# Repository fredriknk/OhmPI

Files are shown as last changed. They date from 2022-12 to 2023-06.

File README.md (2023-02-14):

# OhmPi



Development of a low-cost multi-electrodes resistivity meter for electrical resistivity mesaurement for lab applications, based on raspberry board

## Installation

All dependencies are specified in *requirements.txt*

**Note:** all instructions below should be typed in the terminal

It is first necessary to create an OhmPi virtual environment and install all dependancies
`.create_ohmpi_virtual_envrinment.sh`

When the installation is completed check that requirements are met using 
`pip list`

We strongly recommend users to create a virtual environment to run the code and installed all required dependencies:
*  activate it using the following command:
   `source ohmpy/bin/activate`
*  you should run you code within the virtual environment
*  to leave the virtual environment simply type: `deactivate`

## First run with four electrodes

In the examples folder, you will find the code "simple_measurement.py".

Running this code, in Thonny (IDE) or in the terminal, will allow you to make a simple 4 electrodes measurement A B M N.

## Citing Ohmpi

If you use Ohmpi for you work, please cite [this paper](https://www.sciencedirect.com/science/article/pii/S2468067220300316) as:

    Rémi Clement, Yannick Fargier, Vivien Dubois, Julien Gance, Emile Gros, Nicolas Forquet, OhmPi: An open source data logger for 
    dedicated applications of electrical resistivity imaging at the small and laboratory scale, HardwareX, Volume 8, 2020, e00122, ISSN 2468-0672, https://doi.org/10.1016/j.ohx.2020.e00122..

## License information

You may redistribute and modify this documentation and make products using it under the terms of the CERN-OHL-P v2 (https:/cern.ch/cern-ohl). This documentation is distributed WITHOUT ANY EXPRESS OR IMPLIED WARRANTY, INCLUDING OF MERCHANTABILITY, SATISFACTORY QUALITY AND FITNESS FOR A PARTICULAR PURPOSE. Please see the CERN-OHL-P v2 for applicable conditions

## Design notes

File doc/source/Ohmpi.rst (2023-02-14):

*************** 
OhmPi project 
***************

    Logo OhmPi

|  

**Authors:** 
------------
| Rémi CLEMENT, Vivien DUBOIS, Nicolas Forquet, INRAE, REVERSAAL, Villeurbanne, France
| Yannick FARGIER, GERS-RRO, Univ Gustave Eiffel, IFSTTAR, Lyon, France
| Hélène GUYARD, IGE Grenoble, Université Grenoble Alpes, Grenoble, France
| Olivier KAUFMANN, Arnaud WATLET, Université de Mons, Mons, Belgium
| Guillaume BLANCHY, ILVO, Merelbeke, Belgium|

**Partners:**
-------------

.. table::
   :align: center
  
   +----------------------------------+-----------------------------------+-------------------------------+
   |   
   +----------------------------------+-----------------------------------+-------------------------------+
   |   
   +----------------------------------+-----------------------------------+-------------------------------+

**Citing OhmPi:** 
-----------------

|

*Rémi Clement, Yannick Fargier, Vivien Dubois, Julien Gance, Emile Gros, et al.. OhmPi: An open*
*source data logger for dedicated applications of electrical resistivity imaging at the small and laboratory*
*scale. HardwareX, Elsevier, 2020, 8, 24 p. ff10.1016/j.ohx.2020.e00122ff.*

|
   
**Introduction :** 
-------------------

.. warning::
    **OhmPi is a participative project open to all, it requires skills in electronics and to respect the safety rules. OhmPi must be assembled in a professional context and by people competent in electronics. The OhmPi team cannot be held responsible for any material or human damage which would be associated with the use or the assembly of OhmPi. The OhmPi team cannot be held responsible if the equipment does not work after assembly. You may redistribute and modify this documentation and make products using it under the terms of the CERN-OHL-P v2 (https:/cern.ch/cern-ohl). This documentation is distributed WITHOUT ANY EXPRESS OR IMPLIED WARRANTY, INCLUDING OF MERCHANTABILITY, SATISFACTORY QUALITY AND FITNESS FOR A PARTICULAR PURPOSE. Please see the CERN-OHL-P v2 for applicable conditions   **

|

This documentation presents the development of a low-cost, open hardware \ 
resistivity meter to provide the scientific community with a robust \
and flexible tool for small-scale experiments. Called OhmPi, this basic resistivity meter\
features current injection and measurement functions associated with a multiplexer \
that allows performing automatic measurements with up to 64 electrodes.\
OhmPi's philosophy is to provide a fully open source and open hardware tool\
to the near surface scientific community.

.. note:: 
   Anyone who wants to get involved is welcome to join the OhmPi project!

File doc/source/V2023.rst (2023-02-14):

********************************************
OhmPi V2023 (64 electrodes and 12V)
******************************************** 

.. warning::
  **OhmPi is a participative project open to all, it requires skills in electronics and to respect the safety rules. OhmPi must be assembled in a professional context and by people competent in electronics. The OhmPi team cannot be held responsible for any material or human damage which would be associated with the use or the assembly of OhmPi. The OhmPi team cannot be held responsible if the equipment does not work after assembly.**

OhmPi V: 2023.0.0-rc1

.. note:: 
   In this version, we have developed two new board types that allow the assembly of OhmPi v2023, a measurement board and a multiplexer board.
   This new version is made up of:

   1. A measurement board for four-point measurement

   2. 4 multiplexer cards

   3. A box

  The OhmPi V2023 software has been adapted to handle this new boards and also includes many new functionalities.

The philosophy of OhmPi
========================

The philosophy of OhmPi V2023 is to offer a new DIY multi-electrode resistivity meter. It is a resistivity meter with 64 electrodes, which can be upgraded to 128 electrodes.
It is limited to low-current injection, but suitable for small laboratory experiments and small field time-lapse monitoring.
OhmPi is developed by a team that seeks to share its experience and wishes to improve and offer a more and more robust tool to the community. OhmPi 2023 is completely different version from the previous one. 
We will stop the development on the version V1.0x, to dedicate our efforts on this new version.

=============================================================================================================================================================

Hardware
========

Specifications
--------------

+-------------------------------+-----------------------+-----------+-----------------------+-----------+
| **Parameter**                 |       **V1.0x**       | Units     |       **v2023**       | Units     |
+===============================+=======================+===========+=======================+===========+
|Electrodes                     |32                     |           |64 to 128              |           |
+-------------------------------+-----------------------+-----------+-----------------------+-----------+
|Operating temperature          |-0 to 50               |°c         |-25 to 50              |°C         |
+-------------------------------+-----------------------+-----------+-----------------------+-----------+
|Power consumption of CPU and   |18.5                   |W          |18.5                   |W          |
|control system                 |                       |           |                       |           |
+-------------------------------+-----------------------+-----------+-----------------------+-----------+
|Voltage injection              |12                     |V          |12                     |V          |
+-------------------------------+-----------------------+-----------+-----------------------+-----------+
|Battery                        |9                      |V          |12                     |V          |
+-------------------------------+-----------------------+-----------+-----------------------+-----------+
|Current                        |0 to 40                |mA         |0 to 40                |mA         |
+-------------------------------+-----------------------+-----------+-----------------------+-----------+
|Min pulse duration             |150                    |ms         |150                    |ms         |
+-------------------------------+-----------------------+-----------+-----------------------+-----------+
|Input impedance                |80                     |MOhm       |80                     |MOhm       |
+-------------------------------+-----------------------+-----------+-----------------------+-----------+
|Data storage                   |micro SD card          |           |micro SD card          |           |
+-------------------------------+-----------------------+-----------+-----------------------+-----------+
|Resolution                     |0.01                   |Ohm        |0.01                   |Ohm        |
+-------------------------------+-----------------------+-----------+-----------------------+-----------+

Building an OhmPi V2023 step by step
------------------------------------

.. toctree::
   :maxdepth: 2

   Ohmpi_V2023/V2023_step_01
   Ohmpi_V2023/V2023_step_02
   Ohmpi_V2023/V2023_step_03
   Ohmpi_V2023/V2023_step_04

Software and operation
======================

System architecture
-------------------

The OhmPi V2023 software is designed around a new architecture whose main components are summarized in the figure below.

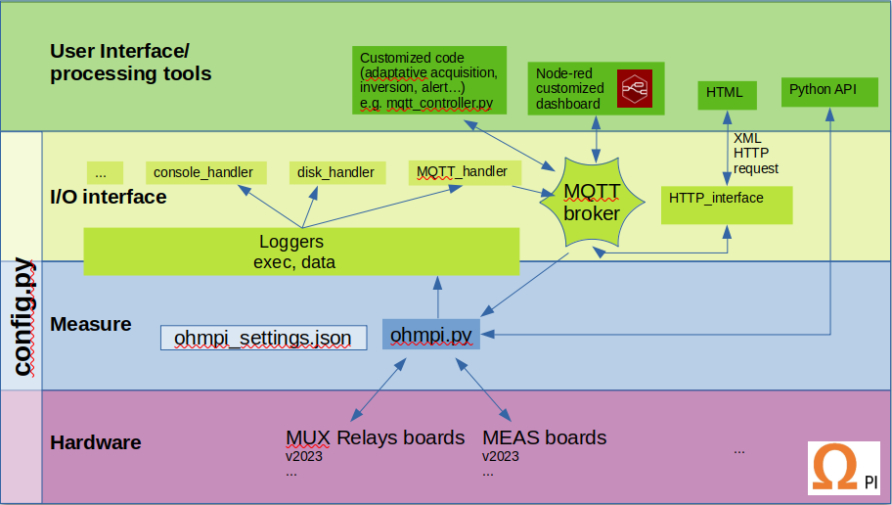
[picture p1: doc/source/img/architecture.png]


     Software architecture of OhmPi V2023.

The general system configuration is defined in the `config.py` file covered in the `Configuration file`_ section.
The acquisition settings (i.e. injection duration, stacks...) are defined in a separate JSON file (default: ohmpi_settings.json).  

The central software component is the ohmpi.py file that contains the OhmPi class that interacts with the hardware. Other python files include utils and handlers (see the `Loggers`_ section for more details).
A communication layer (I/O interface) on top of OhmPi allows for different user interfaces depending on the use cases (see `Interfaces and applications`_).

Loggers
-------

Loggers have been introduced in this release. They use the excellent logging python package.
Specific handlers have been implemented for running with ohmpi.py (one for logging to an mqtt broker (see `MQTT interface`_ for more details) and one for creating zipped rotated logs on disk).

Two loggers have been defined. The first one is dedicated to log operations execution. It is named exec_logger. The second one, named data_logger, is dedicated to log data. A third one is planned to log the state of health (SOH) of the system in a future version.

By default, logs are written to the console (print-like), stored locally in files (a zip is created after some time i.e. every day and/or when the size of the log exceeds a maximum size) and sent to an MQTT broker. Different logging levels may be defined for the different logs and handlers in the `Configuration file`_.

Advanced users may write new handlers and edit the `setup_loggers.py` file to customize the logging mechanisms to their needs.

Configuration file
------------------

The configuration of the OhmPi file `config.py` allows to configure the OhmPi.
A default version of `config.py` is provided in the repository.
This file should be edited to customize the configuration following the user's needs and preferences.  

The configuration includes setting the logging level desired for the different loggers and handlers, setting the mqtt broker(s) used for logging and control of the OhmPi and defining the options used for MQTT communication (i.e. username, password, security options...)  

One should make sure to understand the parameters before altering them. It is also recommended to keep a copy of the default configuration.

Interfaces and applications
---------------------------

Different interfaces can be used to interact with the OhmPi.

Available interfaces are:
- `Web interface`_ (=HTTP interface): run in bash: `bash run_http_interface.sh`
- Python API: import the OhmPi class from Python script: `from ohmpi import OhmPi` (see `Python interface`_)
- MQTT: IoT messaging through a broker (see `MQTT interface`_)

Web interface
.............

This is a user friendly graphical interface for new users as well as running quick and easy acquisitions.

The Raspberry Pi of the OhmPi is used as a Wi-Fi Access Point (AP) and runs
a small webserver to serve the 'index.html' interface. Using a laptop or
a mobile phone connected to the Wi-Fi of the Raspberry Pi, one can see this
interface, upload sequences, change parameters, run a sequence and download data.

To configure the Raspberry Pi to act as an access point and run
the webserver automatically on start, see instructions on `raspap.com <https://raspap.com/>`_ and in 'runOnStart.sh'.

Once configured, the webserver should start by itself on start and once
connected to the Pi, the user can go to `10.3.141.1:8080 <http://10.3.141.1:8080>`_
to access the interface.



    Web interface with its interactive pseudo-section.



     Evolution of quadrupole apparent resistivity with time.



     Contact resistance check.

Python interface
................

This interface offers a more direct access to the software components especially well suited for testing or automation on the Raspberry Pi.

By importing the `OhmPi` class from the ohmpi.py, one can control the OhmPi using interactive IPython.
Typically, it involves using the terminal or an Python IDE such as Thonny on the Raspberry Pi. One can also connect using
ssh and run the Python interface (see PuTTY on Windows or ssh command on macOS/Linux).

To access the Python API, make sure the file ohmpi.py is in the same
directory as where you run the commands/script. The file ohmpi.py can
be found on the OhmPi gitlab repository. We recommend downloading the
entire repository as ohmpi.py import other .py files and default configuration
files (.json and .py).

.. code-block:: python
  :caption: Example of using the Python API to control OhmPi

  import os
  import numpy as np
  import time
  os.chdir("/home/pi/OhmPi")
  from ohmpi import OhmPi

  ### Define object from class OhmPi
  k = OhmPi()  # this loads default parameters from the disk

  ### Default parameters can also be edited manually
  k.settings['injection_duration'] = 0.5  # injection time in seconds
  k.settings['nb_stack'] = 1  # one stack is two half-cycles
  k.settings['nbr_meas'] = 1  # number of time the sequence is repeated

  ### Update settings if needed
  k.update_settings({"injection_duration":0.2})

  ### Set or load sequence
  k.sequence = np.array([[1,2,3,4]])    # set numpy array of shape (n,4)
  # k.set_sequence('1 2 3 4\n2 3 4 5')    # call function set_sequence and pass a string
  # k.load_sequence('ABMN.txt')    # load sequence from a local file

  ### Run contact resistance check
  k.rs_check()

  ### Run sequence (synchronously - it will wait that all
  # sequence is measured before returning the prompt
  k.run_sequence()
  # k.run_sequence_async()  # sequence is run in a separate thread and the prompt returns immediately
  # time.sleep(2)
  # k.interrupt()  # kill the asynchron sequence

  ### Run multiple sequences at given time interval
  k.settings['nb_meas'] = 3  # run sequence three times
  k.settings['sequence_delay'] = 100 # every 100 s
  k.run_multiple_sequences()  # asynchron
  # k.interrupt()  # kill the asynchron sequence

  ### Single measurement can also be taken with
  k.switch_mux_on([1, 4, 2, 3])
  k.run_measurement()  # use default acquisition parameters
  k.switch_mux_off([1, 4, 2, 3])  # don't forget this! risk of short-circuit

  ### Custom or adaptative argument, see help(k.run_measurement)
  k.run_measurement(nb_stack=4,  # do 4 stacks (8 half-cycles)
                    injection_duration=2,  # inject for 2 seconds
                    autogain=True)  # adapt gain of ADS to get good resolution

MQTT interface
..............

This is an interface designed for an advanced remote usage of the OhmPi such as remote automation, data consumption by multiple processes and interaction with other sensors in the scope of a monitoring. It is based on the MQTT protocol, designed for the Internet of Things (IoT), to interact with the OhmPi.  

This option allows interacting remotely with a single OhmPi, a network of OhmPis, as well as auxiliary instruments and sensors. The communication is based on a publish/subscribe approach and involves a MQTT broker.  

An example of MQTT broker that can be used is `Mosquitto <https://mosquitto.org/>`_. Depending on the monitoring needs, an MQTT broker can be set up locally on the Raspberry Pi, on a local network or any remote server reachable through the net. A local Mosquitto broker can be set up and enabled to run as a service on the OhmPi using the bash script install_local_mqtt_broker.sh.  

MQTT messages include logging messages from the OhmPi and commands sent to the OhmPi. These messages can be examined easily using a third party software such as `MQTT Explorer <http://mqtt-explorer.com/>`_.

Commands sent on the broker are received by the ohmpi.py script that runs on the OhmPi (make sure ohmpi.py starts on reboot) and further processed.
MQTT commands are sent in JSON format following the Python API with kwargs as illustrated below:

.. code-block:: json
  :caption: Updating acquisition settings.

  {
    "cmd_id": "3fzxv121UITwGjWYgcz4xw",
    "cmd": "update_settings", Depending on the experiment needs, MQTT brokers can be set up locally on the Raspberry Pi or on a local or remote server.
    "kwargs": {
      "config": {
        "nb_meas": 2,
        "nb_electrodes": 10,
        "nb_stack": 2,
        "injection_duration": 2,
        "sequence_delay": 100
      }
    }
  }

.. code-block:: json
  :caption: Check contact resistances

  {
    "cmd_id": "3fzxv121UITwGjWYgcz4xw",
    "cmd": "rs_check",
  }

.. code-block:: json
  :caption: Running a sequence.

  {
    "cmd_id": "3fzxv121UITwGjWYgcz4Yw",
    "cmd": "run_sequence",
  }

.. code-block:: json
  :caption: Running same sequence multiple times (nb_meas).

  {
    "cmd_id": "3fzxv121UITwGjWYgcz4Yw",
    "cmd": "run_multiple_sequences",
  }

.. code-block:: json
  :caption: Interrupt current acquisition.

  {
    "cmd_id": "3fzxv121UITwGjWYgcz4xw",
    "cmd": "interrupt",
  }

Custom processing of messages and tailor-made dashboards for monitoring experiments may be designed using a browser-based flow editor such as `Node-red <http://mqtt-explorer.com/>`_.
This may help designing complex IoT experiments and monitoring systems in which OhmPi is a component. 

Examples incorporating execution commands and data outputs from OhmPi can be found in the OhmPi examples. Once Node-RED is installed on the OhmPi, these examples can be accessed separately by running a command in the console such as :

.. code-block:: console
     node-red basic_ohmpi_flows_node-red.json

These examples may require installing some additional node packages in order to work properly. This can be done in the `Palette Manager <https://nodered.org/docs/user-guide/editor/palette/manager> within Node-RED.

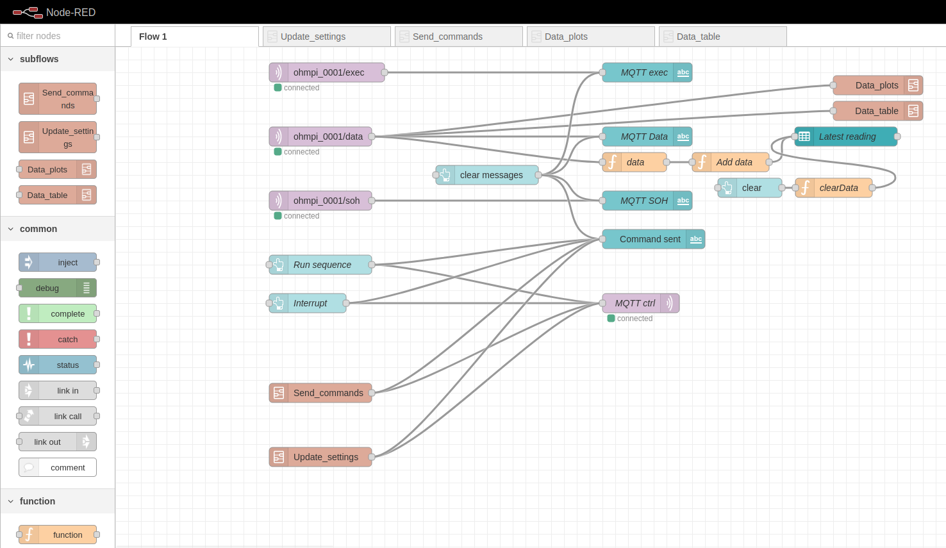
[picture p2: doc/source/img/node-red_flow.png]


     Example flow in node-red to interact with an OhmPi.

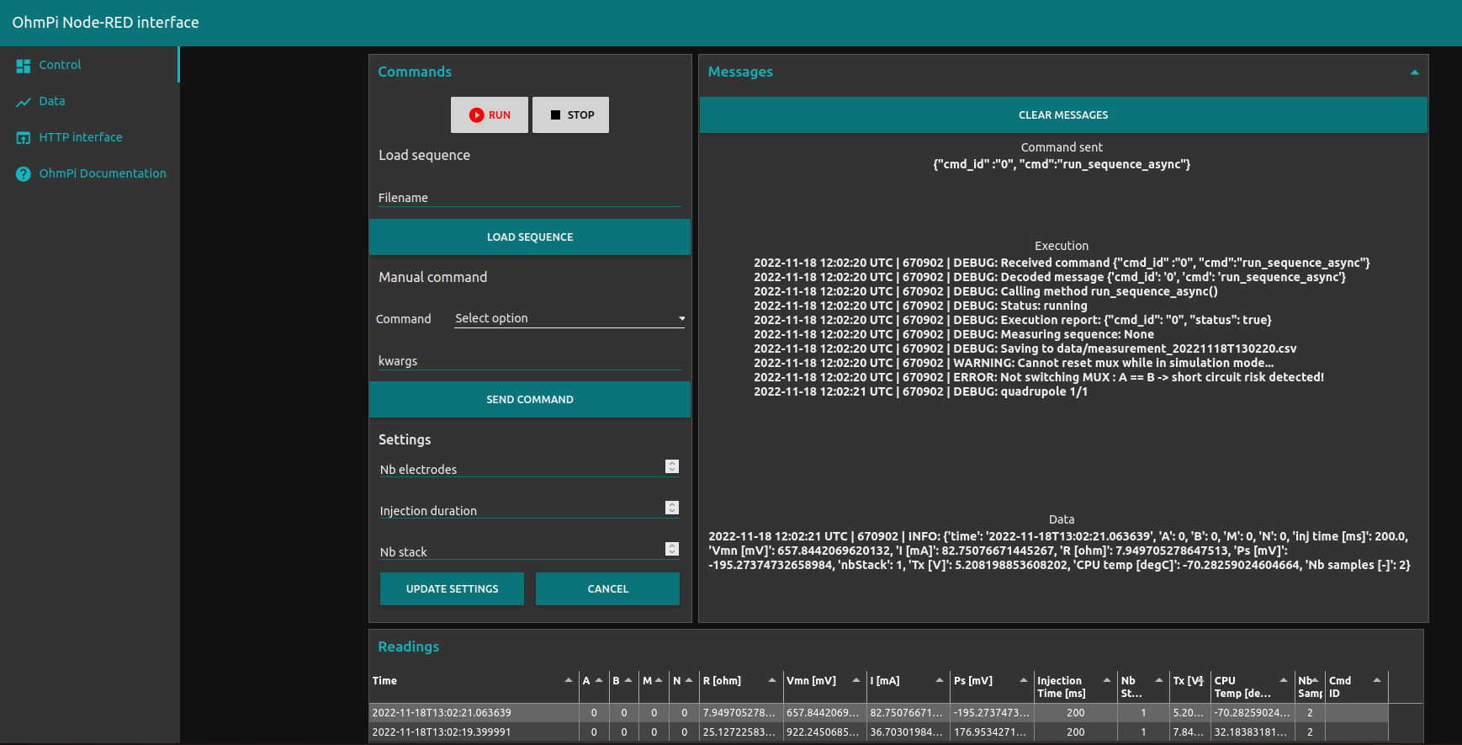
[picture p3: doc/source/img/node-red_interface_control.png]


     Example of a dashboard UI created with node-red to interact with an OhmPi - control tab.
     
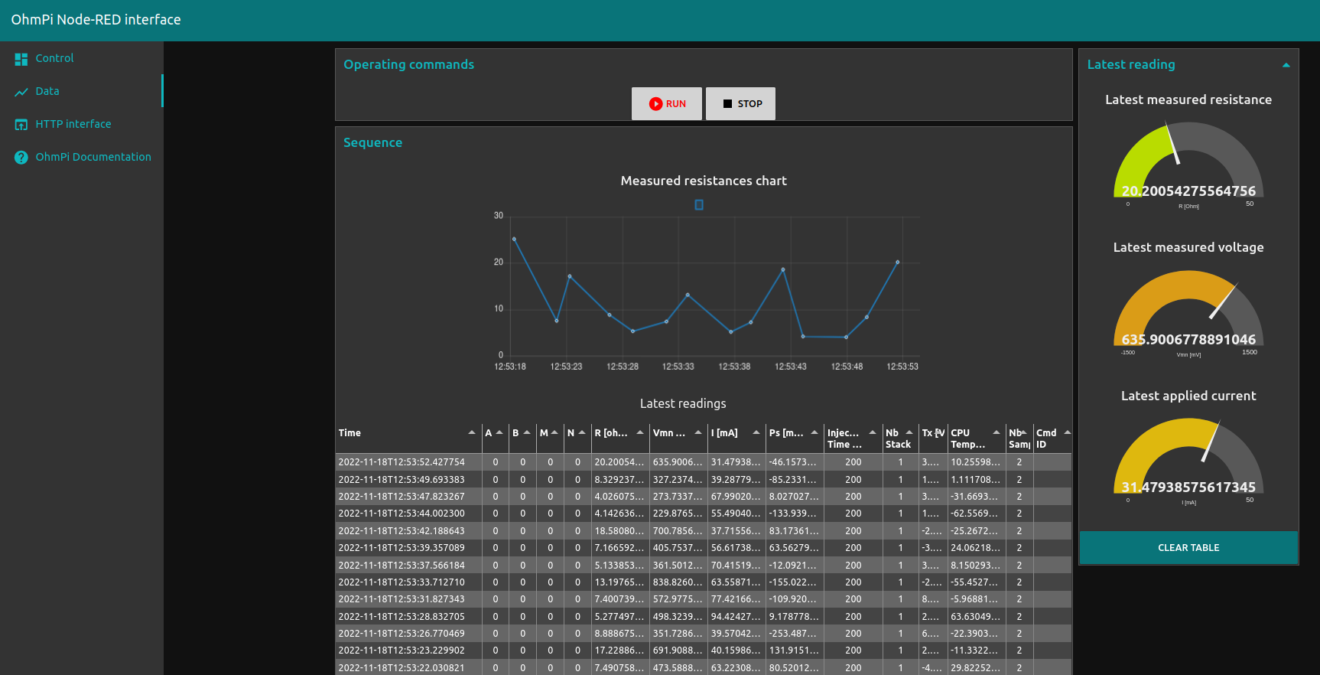
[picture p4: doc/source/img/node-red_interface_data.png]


     Example of a dashboard UI created with node-red to interact with an OhmPi - data visualization tab.

For more documentation dedicated to node-red, please refer to the Node-red `cookbooks <https://cookbook.nodered.org/>`_.

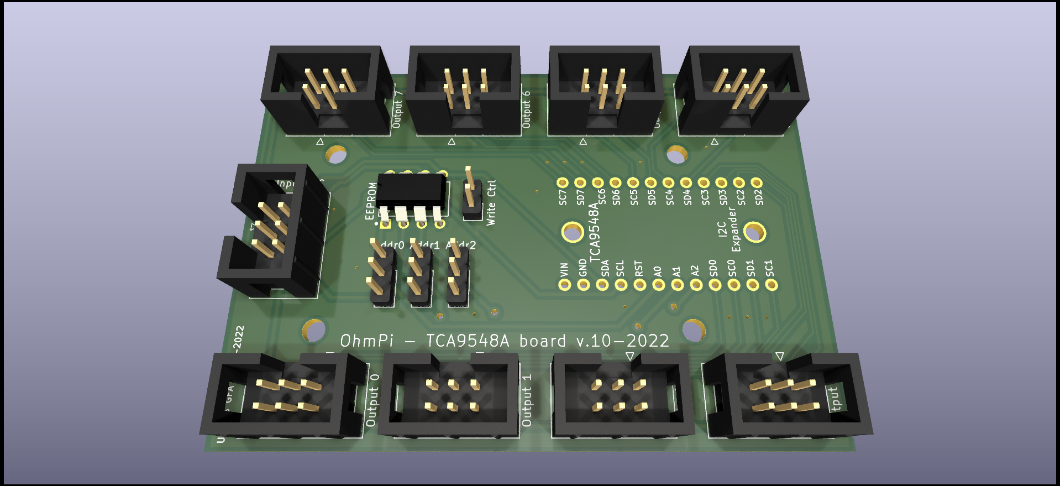
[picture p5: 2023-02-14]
MUX_board/2024.0.0/tca_board/TCA_board_2.png

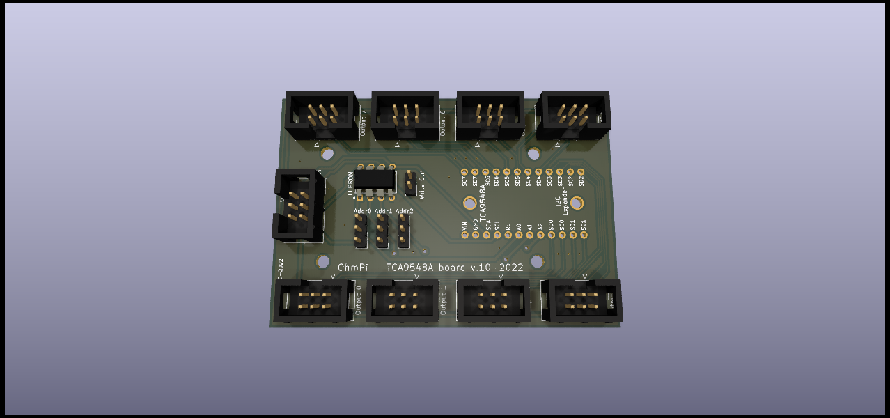
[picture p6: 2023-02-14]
MUX_board/2024.0.0/tca_board/MUX_v2024_tca_board.png

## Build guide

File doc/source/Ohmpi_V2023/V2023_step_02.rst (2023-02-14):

**STEP n°2**: Measurement board
****************************************************

.. warning::
    **Ohmpi is a participative project open to all, it requires skills in electronics and to respect the safety rules. OhmPi must be assembled in a professional context and by people competent in electronics. The OhmPi team cannot be held responsible for any material or human damage which would be associated with the use or the assembly of OHMPI. The OhmPi team cannot be held responsible if the equipment does not work after assembly.**

**PART A** Assembly of the measurement board
======================================================

Required components 
----------------------------------------------------

alternate text

.. csv-table:: List of components
   :file: step_n_2/a/measure_board_list_2_xx.csv
   :widths: 30, 70, 70, 70, 70, 35, 35
   :header-rows: 1
   
Description
------------------  

alternate text

Figure  shows the general schematics for the electronic measurement board developed.
We have developed a complete "plug and play" measurement board. To measure electrical resistivity with Raspberry Pi. 
two ADS1115 were used,one for the voltage measurement one for the current measurement, as proposed by Florsch [7]. The ADS1115
is a 16-bit ADC (Analog-to-Digital Converter), with an adaptable gain. The advantage of ADS1115 is that the 
input signal value could lie between - to + 6.114 V. For the current measurement we have directly integrated the INA282 component, 
which allows to realize precise current measurement around a shunt resistor. The assembly are described in the following steps:

.. table::
   :align: center
   
   +--------+------------------------------------------------------------+
   |        |   
   |      1 +------------------------------------------------------------+
   |        | Installation of female header, 1 by 10  pins, for ADS1115  | 
   |        |                                                            |                                                                       
   +--------+------------------------------------------------------------+
   
.. table::
   :align: center
  
   +--------+------------------------------------------------------------+
   |        |   
   |2       +------------------------------------------------------------+
   |        | Soldering of 4 dual-in-line socket (2 by 2 pins) for       | 
   |        | optical relay, AQY211EH.                                   |                                                                       
   +--------+------------------------------------------------------------+
   
.. table::
   :align: center
  
   +--------+------------------------------------------------------------+
   |        |   
   |3       +------------------------------------------------------------+
   |        | Soldering of 1 dual-in-line socket (2 by 9 pins)           | 
   |        | for MCP23008.                                              |                                                                       
   +--------+------------------------------------------------------------+
   
.. table::
   :align: center
  
   +--------+------------------------------------------------------------+
   |        |   
   | 4      +------------------------------------------------------------+
   |        | Soldering of 1 dual-in-line socket (2 by 4 pins)           | 
   |        |                                                            |                                                                       
   +--------+------------------------------------------------------------+ 
.. table::
   :align: center
  
   +--------+------------------------------------------------------------+
   |        |   
   |5       +------------------------------------------------------------+
   |        | Soldering of 2 dual-in-line socket (2 by 4 pins)           | 
   |        |                                                            |                                                                       
   +--------+------------------------------------------------------------+
   
.. table::
   :align: center
  
   +--------+------------------------------------------------------------+
   |        |   
   | 6      +------------------------------------------------------------+
   |        | Traco Power Supply 12V to 5V, TDH15 - 1211N                | 
   |        |                                                            |                                                                       
   +--------+------------------------------------------------------------+  

.. table::
   :align: center
  
   +--------+------------------------------------------------------------+
   |        |   
   |7       +------------------------------------------------------------+
   |        | Four screw terminals for 12V inpout et 5V output           |
   |        |                                                            |                                                                       
   +--------+------------------------------------------------------------+
   
.. table::
   :align: center
  
   +--------+------------------------------------------------------------+
   |        |   
   |8       +------------------------------------------------------------+
   |        | Traco power Supply 12V to 24V, TRN-1215                    | 
   |        |                                                            |                                                                       
   +--------+------------------------------------------------------------+    

.. table::
   :align: center
  
   +--------+------------------------------------------------------------+
   |        |   
   |9       +------------------------------------------------------------+
   |        | Two screw terminals electrodes M and N                     | 
   |        |                                                            |                                                                       
   +--------+------------------------------------------------------------+
   
.. table::
   :align: center
  
   +---------+------------------------------------------------------------+
   |         |   
   |10       +------------------------------------------------------------+
   |         | Four screw terminals, for 12V power supply and for         | 
   |         | electrodes A and B                                         |                                                                       
   +---------+------------------------------------------------------------+

.. table::
   :align: center
  
   +---------+------------------------------------------------------------+
   |         |   
   |11       +------------------------------------------------------------+
   |         |  Soldering three capacitors (100nF)                        | 
   |         |                                                            |                                                                       
   +---------+------------------------------------------------------------+

.. warning::
     
     In this version, we used a shunt resistor of 2 ohms, which limits the current measurement to 48 mA. If the current is higher than this value, you just have to decrease the value of the shunt resistor. Don't forget to change the shunt value in the config.py file (value associated to key 'R_shunt' in the OHMPI_CONFIG dict).

.. table::
   :align: center
  
   +---------+------------------------------------------------------------+
   |         |   
   | 12      +------------------------------------------------------------+
   |         | 2 ohms shunt resistor pre-adjustment                       | 
   |         |                                                            |                                                                       
   +---------+------------------------------------------------------------+
.. table::
   :align: center
  
   +---------+------------------------------------------------------------+
   |         |   
   |13       +------------------------------------------------------------+
   |         | Soldering 2 ohms shunt resistor                            | 
   |         |                                                            |                                                                       
   +---------+------------------------------------------------------------+
   
.. table::
   :align: center
  
   +---------+------------------------------------------------------------+
   |         |   
   |14       +------------------------------------------------------------+
   |         | 1 MOhm resistors                                          |
   |         |                                                            |                                                                       
   +---------+------------------------------------------------------------+  
   
.. table::
   :align: center
  
   +---------+------------------------------------------------------------+
   |         |   
   |15       +------------------------------------------------------------+
   |         | Soldering tow 1 kOhm resistors                            |
   |         |                                                            |                                                                       
   +---------+------------------------------------------------------------+
   
.. table::
   :align: center
  
   +---------+------------------------------------------------------------+
   |         |   
   |16       +------------------------------------------------------------+
   |         | Soldering two 1.5 kOhm resistors                           |
   |         |                                                            |                                                                       
   +---------+------------------------------------------------------------+
.. table::
   :align: center
  
   +---------+------------------------------------------------------------+
   |         |   
   |17       +------------------------------------------------------------+
   |         | Soldering two 1.5 kOhms resistors                          |
   |         |                                                            |                                                                       
   +---------+------------------------------------------------------------+
   
.. table::
   :align: center
  
   +---------+------------------------------------------------------------+
   |         |   
   |18       +------------------------------------------------------------+
   |         | Female header 2 by 20 pins for Raspberry Pi connection     | 
   |         |                                                            |                                                                       
   +---------+------------------------------------------------------------+

.. table::
   :align: center
  
   +---------+------------------------------------------------------------+
   |         |   
   |19       +------------------------------------------------------------+
   |         | View of the female  header 2 by 20 pins installation       | 
   |         | for Raspberry Pi connection                                |                                                                       
   +---------+------------------------------------------------------------+
   
.. table::
   :align: center
  
   +---------+------------------------------------------------------------+
   |         |   
   |20       +------------------------------------------------------------+
   |         | Fixing MCP23008 component (Dot mark on the top left corner)| 
   |         |                                                            |                                                                       
   +---------+------------------------------------------------------------+
   
.. table::
   :align: center
  
   +---------+------------------------------------------------------------+
   |         |   
   |21       +------------------------------------------------------------+
   |         |Mounting optical relay, AQY211EH (Dot mark in the top left  | 
   |         |corners)                                                    |                                                                       
   +---------+------------------------------------------------------------+
   
.. table::
   :align: center
  
   +---------+------------------------------------------------------------+
   |         |   
   |22       +------------------------------------------------------------+
   |         | Mounting LM158 operational amplifier                       |
   |         |                                                            |                                                                       
   +---------+------------------------------------------------------------+

.. table::
   :align: center
  
   +---------+------------------------------------------------------------+
   |         |   
   |23       +------------------------------------------------------------+
   |         |  Mounting ADS115 board                                     | 
   |         |                                                            |                                                                       
   +---------+------------------------------------------------------------+
   
.. table::
   :align: center
  
   +---------+------------------------------------------------------------+
   |         |   
   |24       +------------------------------------------------------------+
   |         | Fixing the INA282 (Dot mark in the top right corner)       | 
   |         |                                                            |                                                                       
   +---------+------------------------------------------------------------+

**PART B** Start-up of the measurement board
====================================================== 

+------------------------------------------------------------------------+
| **Required components**                                                | 
+------------------------------------------------------------------------+

.. csv-table:: List of components
   :file: step_n_2/b/test_2_xx.csv
   :widths: 30, 70, 70, 70, 70, 35, 35
   :header-rows: 1

.. table::
   :align: center
   
   +--------+------------------------------------------------------------+
   |        |   
   |1       +------------------------------------------------------------+
   |        | Shutdown the raspberry Pi and unplug the power supply      | 
   |        |                                                            |                                                                       
   +--------+------------------------------------------------------------+
   
.. table::
   :align: center
   
   +--------+--------------------------------------------------------------------------+
   |        |   
   |2       +--------------------------------------------------------------------------+
   |        | Mounting the bottom spacers on the Raspberry Pi (male/female, 11mm, M3)  | 
   |        |                                                                          |                                                                       
   +--------+--------------------------------------------------------------------------+

.. table::
   :align: center
   
   +--------+--------------------------------------------------------------------------+
   |        |   
   |3       +--------------------------------------------------------------------------+
   |        | Mounting the upper spacers on the Raspberry Pi (female/female, 11mm, M3) | 
   |        |                                                                          |                                                                       
   +--------+--------------------------------------------------------------------------+

.. table::
   :align: center
   
   +--------+------------------------------------------------------------+
   |        |   
   |4       +------------------------------------------------------------+
   |        | Mounting the OhmPi's measurement board on the Raspberry Pi | 
   |        |                                                            |                                                                       
   +--------+------------------------------------------------------------+

.. table::
   :align: center
   
   +--------+------------------------------------------------------------+
   |        |   
   |5       +------------------------------------------------------------+
   |        | Mounting the OhmPi's measurement board on the Raspberry Pi | 
   |        |                                                            |
   +--------+------------------------------------------------------------+   

.. table::
   :align: center
   
   +--------+------------------------------------------------------------+
   |        |   
   |6       +------------------------------------------------------------+
   |        | Plug the power supply into a socket and connect it to your | 
   |        | Raspberry Pi's power port.                                 |
   +--------+------------------------------------------------------------+  

**PART C** Check the measurement board
====================================================== 

 Run the terminal, and write

 .. code-block:: python

     i2cdetect -y 1

.. table::
   :align: center
   
   +--------+------------------------------------------------------------+
   |        |   
   |1       +------------------------------------------------------------+
   |        |If everything is working, three I2C addresses should appear | 
   |        |on the screen.                                              |                                                                       
   +--------+------------------------------------------------------------+

Setting up an equivalent electronic circuit, for this you will need: 
 * 4 1kOhm resistor (R2)
 * 1 220 Ohm resistor (R1)
 * 1 small padboard
 * Spool of solder
 
 .. table::
   :align: left
 
   +--------+------------------------------------------------------------+
   |        |   
   |2       +------------------------------------------------------------+
   |        | Schematic of equivalent electronic circuit test            |                                                                       
   +--------+------------------------------------------------------------+
   
.. table::
   :align: center
 
   +--------+------------------------------------------------------------+
   |        |   
   |3       +------------------------------------------------------------+
   |        | Prepare the equivalent electronic circuit test             |                                                                       
   +--------+------------------------------------------------------------+ 

.. table::
   :align: center
 
   +--------+------------------------------------------------------------+
   |        |   
   |4       +------------------------------------------------------------+
   |        |  Prepare the battery connections and the terminals.        |                                                                       
   +--------+------------------------------------------------------------+ 

.. table::
   :align: center
 
   +--------+------------------------------------------------------------+
   |        |   
   |5       +------------------------------------------------------------+
   |        | Soldering cables and terminals                             |                                                                       
   +--------+------------------------------------------------------------+ 

.. table::
   :align: center
 
   +--------+------------------------------------------------------------+
   |        |   
   |6       +------------------------------------------------------------+
   |        |Install the red cables on the +12V terminal and black cable |                                                                       
   |        |on the ground terminal. Connect to two different 12V        |
   |        |batteries                                                   |
   +--------+------------------------------------------------------------+ 

.. table::
   :align: center
 
   +--------+------------------------------------------------------------+
   |        |   
   |7       +------------------------------------------------------------+
   |        | Connect the equivalent electronic circuit test             |                                                                       
   |        |                                                            |
   +--------+------------------------------------------------------------+

.. table::
   :align: center
 
   +--------+------------------------------------------------------------+
   |        |   
   |7       +------------------------------------------------------------+
   |        | Run the Thonny Interpreter                                 |                    
   |        |                                                            |
   +--------+------------------------------------------------------------+   

.. table::
   :align: center
 
   +--------+------------------------------------------------------------+
   |        |   
   |7       +------------------------------------------------------------+
   |        | Run sample_measurement_example.py example, if everything   |                    
   |        | works you should  get the following result (220 Ohm)       |
   +--------+------------------------------------------------------------+

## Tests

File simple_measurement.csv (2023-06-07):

time | A | B | M | N | inj time [ms] | Vmn [mV] | I [mA] | R [ohm] | Ps [mV] | nbStack | Tx [V] | CPU temp [degC] | Nb samples [-] | I_stack [mA] | I_std [mA] | I_per_stack [mA] | Vmn_stack [mV] | Vmn_std [mV] | Vmn_per_stack [mV] | R_stack [ohm] | R_std [ohm] | R_per_stack [ohm] | PS_per_stack [mV] | PS_stack [mV] | R_ab [ohm] | Gain_Vmn | i0 | i1 | i2 | i3 | i4 | i5 | i6 | i7 | i8 | i9 | i10 | i11 | i12 | i13 | i14 | i15 | i16 | i17 | i18 | i19 | i20 | i21 | i22 | i23 | i24 | i25 | i26 | i27 | i28 | i29 | i30 | i31 | i32
2023-06-07T09:46:37.882939 | 20 | 23 | 21 | 22 | 509.0169906616211 | -522.2711467838577 | 50.539153939721565 | -10.333990699701355 | 36.50632241787978 | 3 | 50.0 | 54.768 | 251 | 50.53915393972158 | 0.015950185919994617 | [50.53660922 50.54377462 50.53707798] | -521.9032040075163 | 3.377103080569082 | [-522.13088953 -521.5360053 -522.04271719] | -10.326710348772242 | -0.06690095183556873 | [-10.32723034 -10.32576629 -10.32713455] | [36.48214013 36.38280674 36.3336981 ] | 36.3995483260598 | 1464.84375 | 4 | 50.52716696676534 | 50.553417767876205 | 50.547792596209604 | 50.56091799676503 | 50.545917538987396 | 50.50091616565448 | 50.521541795098734 |
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

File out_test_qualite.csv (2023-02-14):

time | A | B | M | N | inj time [ms] | Vmn [mV] | I [mA] | R [ohm] | Ps [mV] | nbStack | Tx [V] | CPU temp [degC] | Nb samples [-] | i0 | i1 | i2 | i3 | i4 | i5 | i6 | i7 | i8 | i9 | i10 | i11 | i12 | i13 | i14 | i15 | i16 | i17 | i18 | i19 | i20 | i21 | i22 | i23 | i24 | i25 | i26 | i27 | i28 | i29 | i30 | i31 | i32 | i33 | i34 | i35 | i36 | i37 | i38 | i39 | i40 | i41 | i42 | i43 | i44 | i45
2023-02-14T14:01:53.574214 | 1 | 2 | 3 | 4 | 1001.3916492462158 | 494.1635181737724 | 45.57058366874879 | 10.843914613116045 | 6.843958861049231 | 2 | 18.664368822909914 | 46.698 | 101 | 43.80133671071505 | 43.83133762627033 | 43.840712912381356 | 43.88008911404767 | 43.85008819849239 | 43.842587969603564 | 43.81258705404828 | 43.919465315713985 | 43.85008819849239 | 43.85008819849239 | 43.84821314127018 | 43.94946623126927 | 43.865088656270025 | 43.8538383129368 | 43.85008819849239 | 43.86696371349223 | 43.86696371349223 | 43.91571520126958 | 43.9250904873806 | 43.91196508682517 | 43.9250904873806 | 43.829462569048125 | 43.89883968626973 | 43.863213599047825 | 43.90633991515854 | 43.88008911404767 | 43.9250904873806 | 43.842587969603564 | 43.855713370159 | 43.91196508682517 |
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

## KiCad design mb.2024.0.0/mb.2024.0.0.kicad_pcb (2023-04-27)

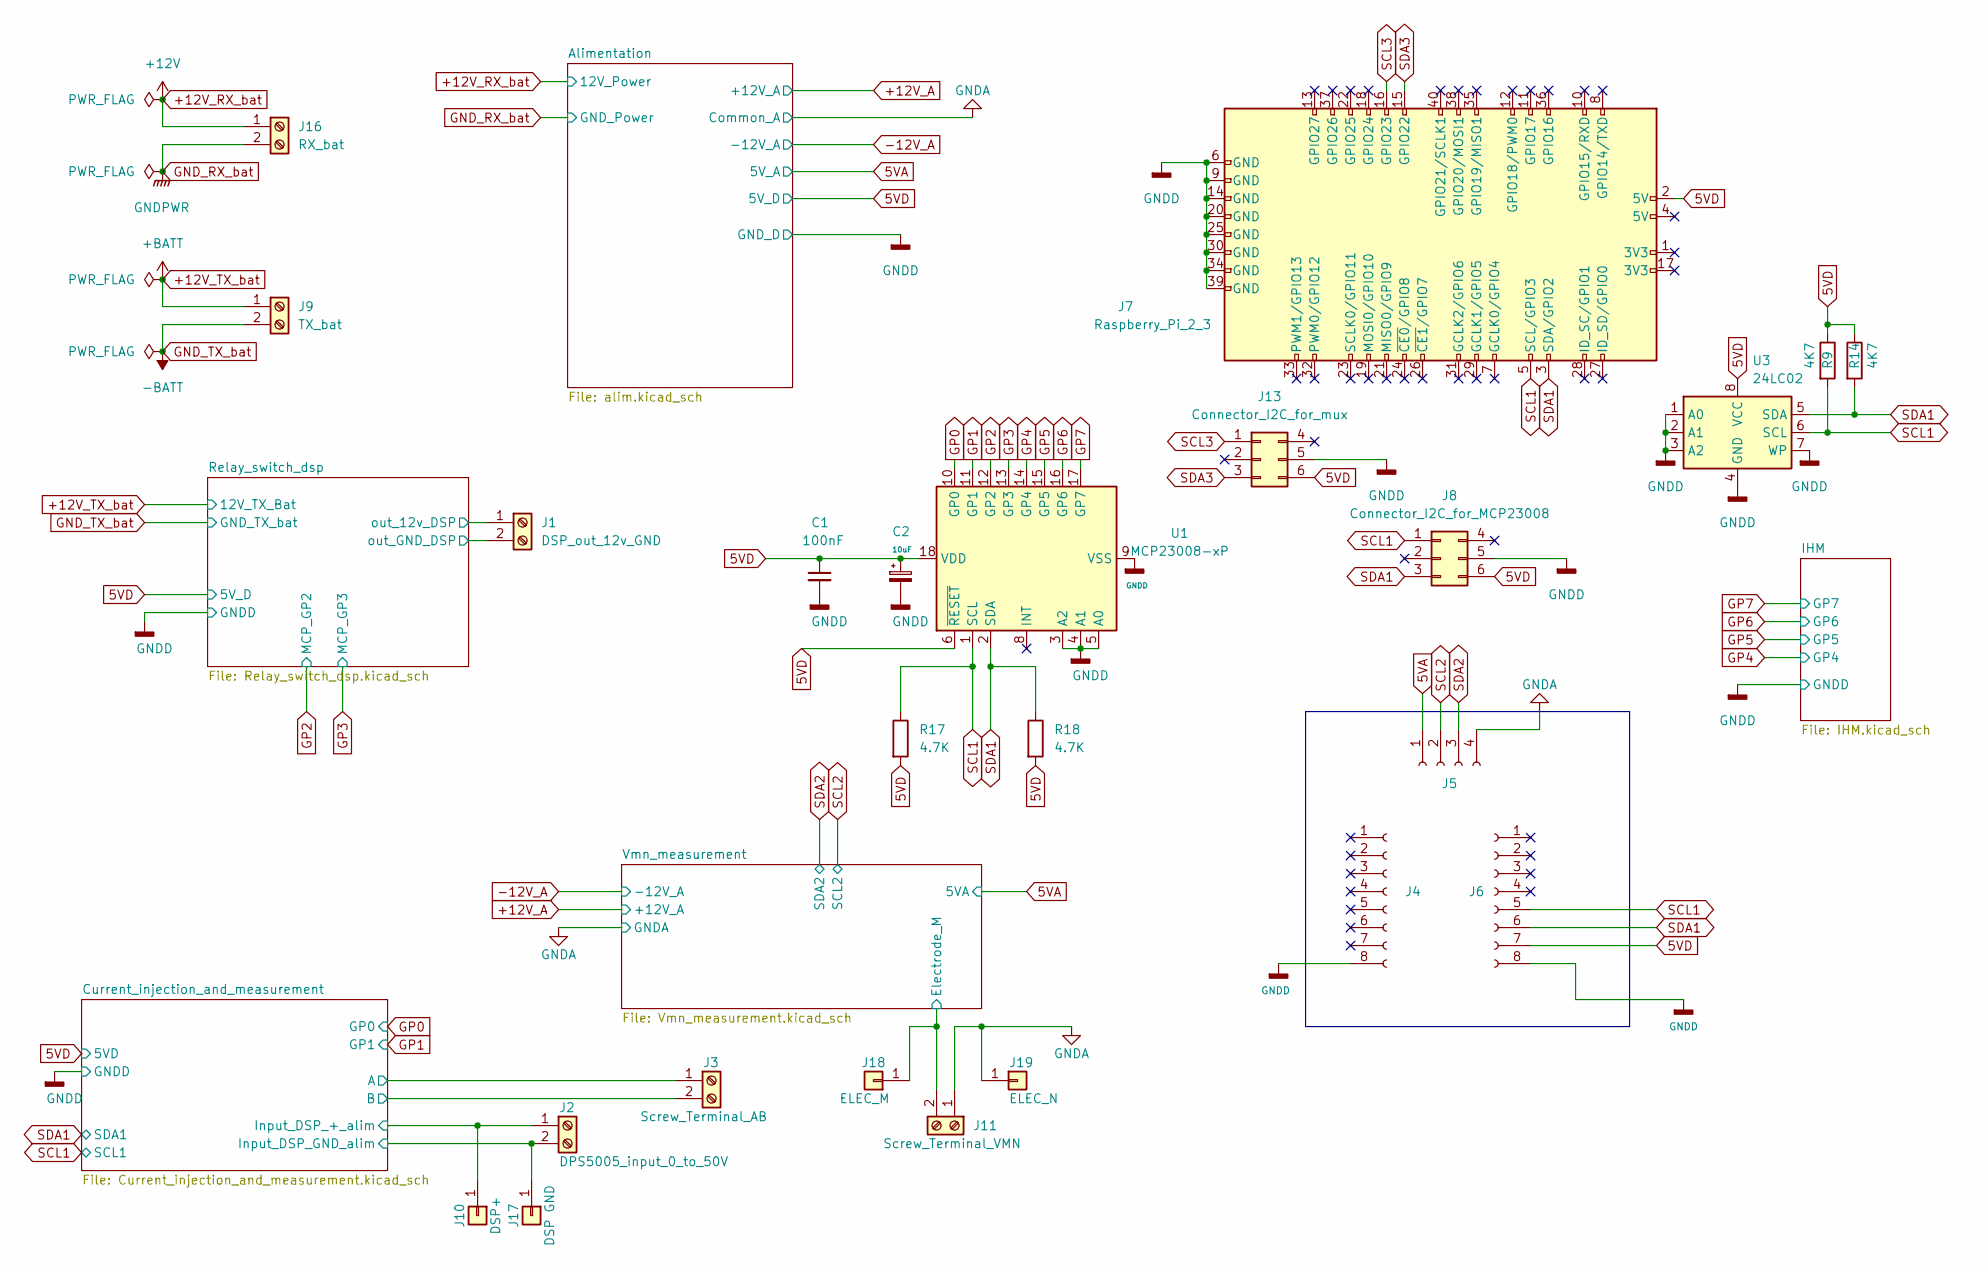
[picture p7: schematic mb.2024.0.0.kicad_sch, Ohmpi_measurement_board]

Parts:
C1: 100nF; C_Disc_D8.0mm_W2.5mm_P5.00mm
C2: 10uF; CP_Radial_D6.3mm_P2.50mm
J1: DSP_out_12v_GND; TerminalBlock_Phoenix_MKDS-1,5-2-5.08_1x02_P5.08mm_Horizont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
J2: DPS5005_input_0_to_50V; TerminalBlock_Phoenix_MKDS-1,5-2-5.08_1x02_P5.08mm_Horizont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
J3: Screw_Terminal_AB; TerminalBlock_Phoenix_MKDS-1,5-2-5.08_1x02_P5.08mm_Horizont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
J4, J6: Conn_01x08_Female; PinHeader_1x08_P2.54mm_Vertical
J5: Conn_01x04_Female; PinHeader_1x04_P2.54mm_Vertical
J7: Raspberry_Pi_2_3; PinSocket_2x20_P2.54mm_Vertical
J8: Connector_I2C_for_MCP23008; IDC-Header_2x03_P2.54mm_Vertical
J9: TX_bat; TerminalBlock_Phoenix_MKDS-1,5-2-5.08_1x02_P5.08mm_Horizont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
J10: DSP+; PinHeader_1x01_P2.54mm_Vertical
J11: Screw_Terminal_VMN; TerminalBlock_Phoenix_MKDS-1,5-2-5.08_1x02_P5.08mm_Horizont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
J13: Connector_I2C_for_mux; IDC-Header_2x03_P2.54mm_Vertical
J16: RX_bat; TerminalBlock_Phoenix_MKDS-1,5-2-5.08_1x02_P5.08mm_Horizont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
J17: DSP GND; PinHeader_1x01_P2.54mm_Vertical
J18: ELEC_M; PinHeader_1x01_P2.54mm_Vertical
J19: ELEC_N; PinHeader_1x01_P2.54mm_Vertical
R9, R14: 4K7; R_Axial_DIN0204_L3.6mm_D1.6mm_P7.62mm_Horizontal
R17, R18: 4.7K; R_Axial_DIN0207_L6.3mm_D2.5mm_P7.62mm_Horizontal
U1: MCP23008-xP; DIP-18_W7.62mm
U3: 24LC02; DIP-8_W7.62mm

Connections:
5VA: J5.1; also elsewhere on the board
5VD: C1.1, C2.1, J6.7, J7.2 (5V), J8.6, J13.6, R9.1, R14.1, R17.2, R18.2, U1.6 (~RESET), U1.18 (VDD), U3.8 (VCC); also elsewhere on the board
+12V_RX_bat: J16.1; also elsewhere on the board
+12V_TX_bat: J9.1; also elsewhere on the board
/Current_injection_and_measurement/A: J3.1; also elsewhere on the board
/Current_injection_and_measurement/B: J3.2; also elsewhere on the board
/Current_injection_and_measurement/Input_DSP_+_alim: J2.1, J10.1; also elsewhere on the board
/Current_injection_and_measurement/Input_DSP_GND_alim: J2.2, J17.1; also elsewhere on the board
/Relay_switch_dsp/out_12v_DSP: J1.1; also elsewhere on the board
/Relay_switch_dsp/out_GND_DSP: J1.2; also elsewhere on the board
/Vmn_measurement/Electrode_M: J11.2, J18.1; also elsewhere on the board
GNDA: J5.4, J11.1, J19.1; also elsewhere on the board
GNDD: C1.2, C2.2, J4.8, J6.8, J7.6 (GND), J7.9 (GND), J7.14 (GND), J7.20 (GND), J7.25 (GND), J7.30 (GND), J7.34 (GND), J7.39 (GND), J8.5, J13.5, U1.3 (A2), U1.4 (A1), U1.5 (A0), U1.9 (VSS), U3.1 (A0), U3.2 (A1), U3.3 (A2), U3.4 (GND), U3.7 (WP); also elsewhere on the board
GND_RX_bat: J16.2; also elsewhere on the board
GND_TX_bat: J9.2; also elsewhere on the board
GP0: U1.10 (GP0); also elsewhere on the board
GP1: U1.11 (GP1); also elsewhere on the board
GP2: U1.12 (GP2); also elsewhere on the board
GP3: U1.13 (GP3); also elsewhere on the board
GP4: U1.14 (GP4); also elsewhere on the board
GP5: U1.15 (GP5); also elsewhere on the board
GP6: U1.16 (GP6); also elsewhere on the board
GP7: U1.17 (GP7); also elsewhere on the board
SCL1: J6.5, J7.5 (SCL/GPIO3), J8.1, R9.2, R17.1, U1.1 (SCL), U3.6 (SCL); also elsewhere on the board
SCL2: J5.2; also elsewhere on the board
SCL3: J7.16 (GPIO23), J13.1
SDA1: J6.6, J7.3 (SDA/GPIO2), J8.3, R14.2, R18.1, U1.2 (SDA), U3.5 (SDA); also elsewhere on the board
SDA2: J5.3; also elsewhere on the board
SDA3: J7.15 (GPIO22), J13.3

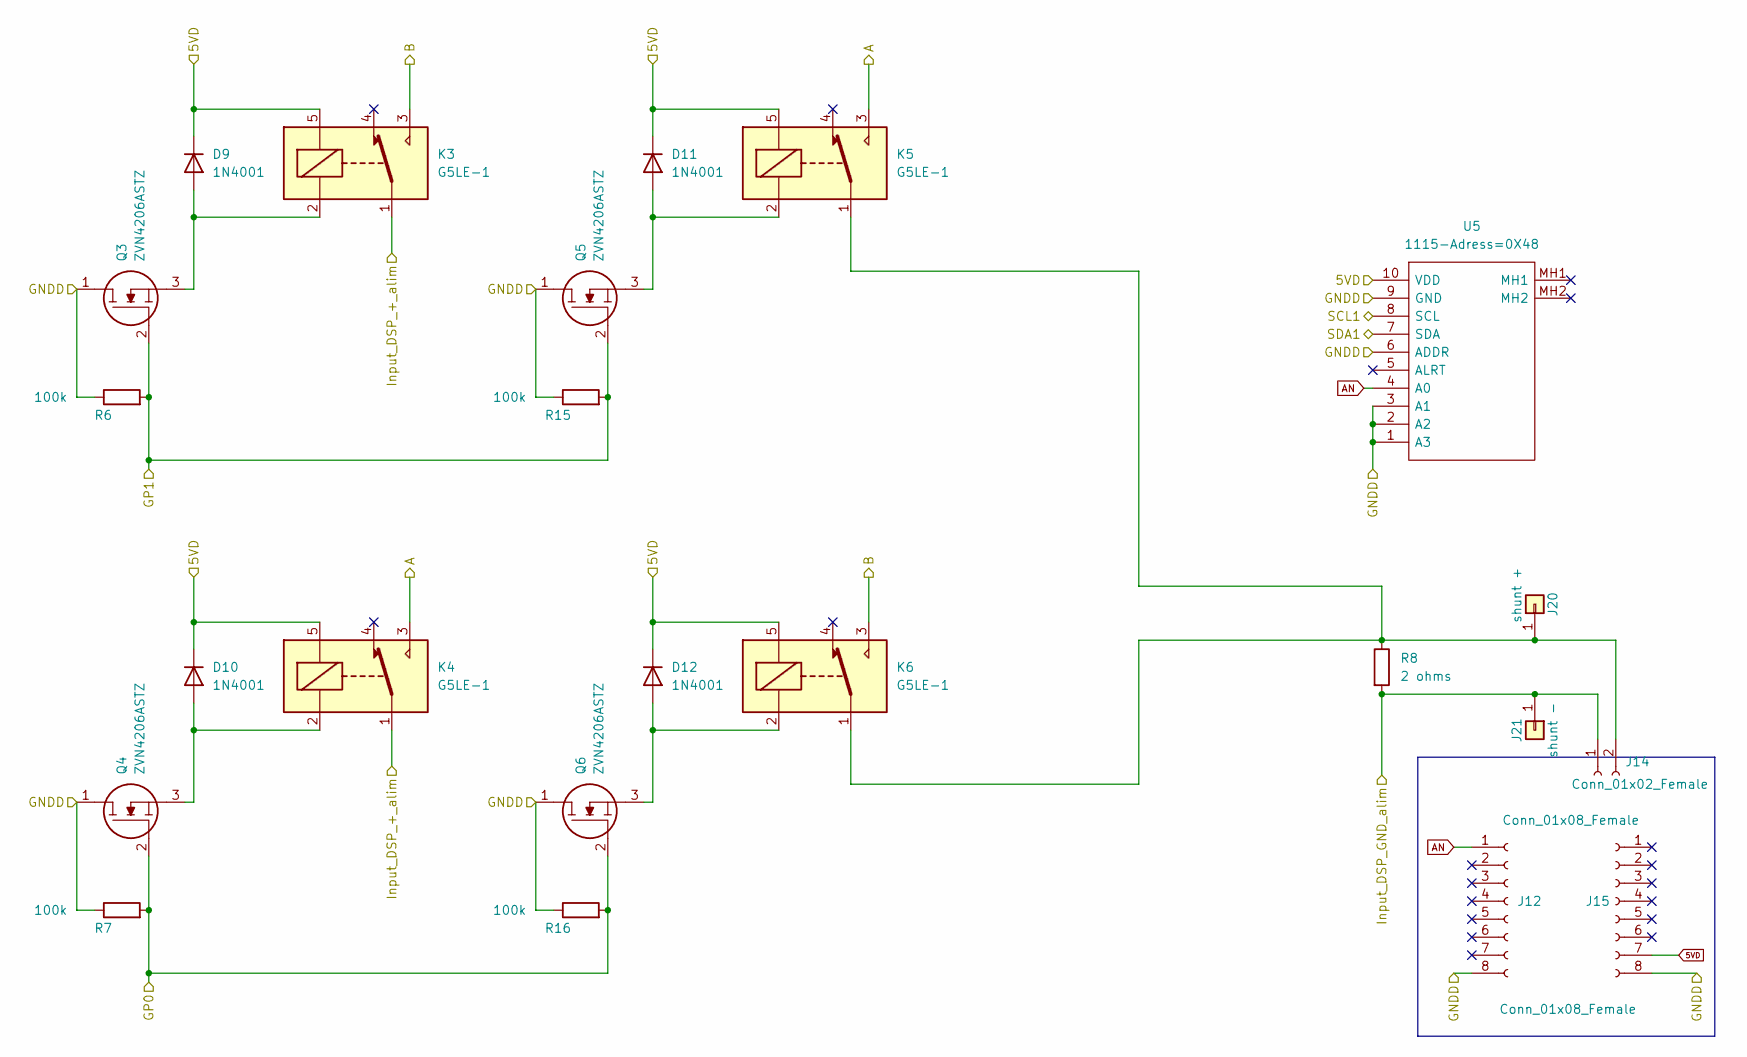
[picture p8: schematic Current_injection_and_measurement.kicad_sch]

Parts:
D9, D10, D11, D12: 1N4001; D_DO-41_SOD81_P10.16mm_Horizontal
J12, J15: Conn_01x08_Female; PinHeader_1x08_P2.54mm_Vertical
J14: Conn_01x02_Female; PinHeader_1x02_P2.54mm_Vertical
J20: shunt +; PinHeader_1x01_P2.54mm_Vertical
J21: shunt -; PinHeader_1x01_P2.54mm_Vertical
K3, K4, K5, K6: G5LE-1; Relay_SPDT_Omron-G5LE-1
Q3, Q4, Q5, Q6: ZVN4206ASTZ; TO-92L_Wide; Manufacturer_Part_Number ZVN4206ASTZ; Mouser Part Number 522-ZVN4206ASTZ
R6, R7, R15, R16: 100k; R_Axial_DIN0207_L6.3mm_D2.5mm_P7.62mm_Horizontal
R8: 2 ohms; R_Axial_DIN0414_L11.9mm_D4.5mm_P20.32mm_Horizontal
U5: 1115-Adress=0X48; 1085; PARTREV N/A; Mouser Part Number 485-1085

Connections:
5VD: D9.1 (K), D10.1 (K), D11.1 (K), D12.1 (K), J15.7, K3.5, K4.5, K5.5, K6.5, U5.10 (VDD); also elsewhere on the board
/Current_injection_and_measurement/A: K4.3, K5.3; also elsewhere on the board
/Current_injection_and_measurement/B: K3.3, K6.3; also elsewhere on the board
/Current_injection_and_measurement/Input_DSP_+_alim: K3.1, K4.1; also elsewhere on the board
/Current_injection_and_measurement/Input_DSP_GND_alim: J14.1, J21.1, R8.2; also elsewhere on the board
AN: J12.1, U5.4 (A0)
GNDD: J12.8, J15.8, Q3.1, Q4.1, Q5.1, Q6.1, R6.1, R7.1, R15.1, R16.1, U5.1 (A3), U5.2 (A2), U5.3 (A1), U5.6 (ADDR), U5.9 (GND); also elsewhere on the board
GP0: Q4.2, Q6.2, R7.2, R16.2; also elsewhere on the board
GP1: Q3.2, Q5.2, R6.2, R15.2; also elsewhere on the board
unnamed: D9.2 (A), K3.2, Q3.3
unnamed: D10.2 (A), K4.2, Q4.3
unnamed: D11.2 (A), K5.2, Q5.3
unnamed: D12.2 (A), K6.2, Q6.3
unnamed: J14.2, J20.1, K5.1, K6.1, R8.1
SCL1: U5.8 (SCL); also elsewhere on the board
SDA1: U5.7 (SDA); also elsewhere on the board

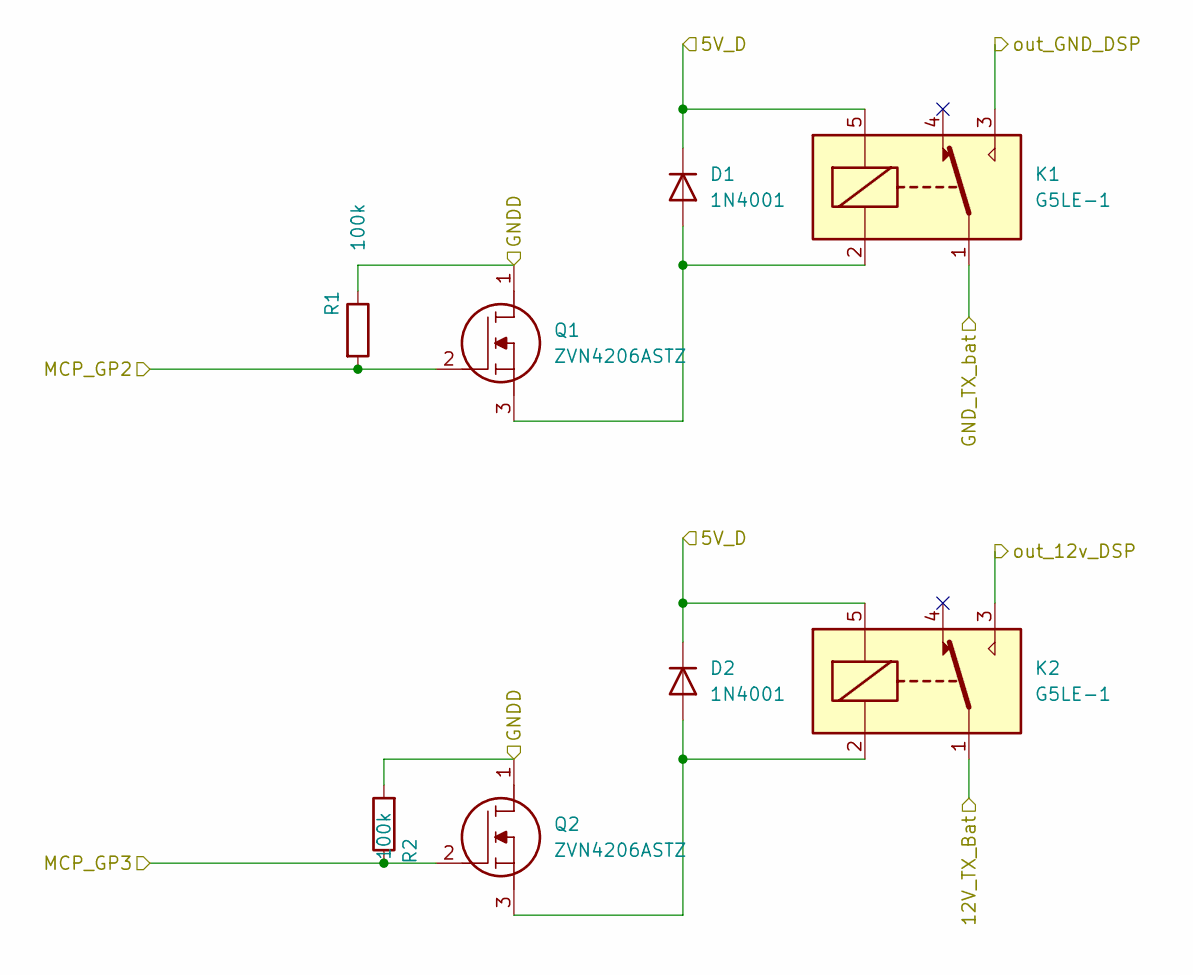
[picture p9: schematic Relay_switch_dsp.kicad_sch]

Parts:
D1, D2: 1N4001; D_DO-41_SOD81_P10.16mm_Horizontal
K1, K2: G5LE-1; Relay_SPDT_Omron-G5LE-1
Q1, Q2: ZVN4206ASTZ; TO-92L_Wide; Manufacturer_Part_Number ZVN4206ASTZ; Mouser Part Number 522-ZVN4206ASTZ
R1, R2: 100k; R_Axial_DIN0207_L6.3mm_D2.5mm_P7.62mm_Horizontal

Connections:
5VD: D1.1 (K), D2.1 (K), K1.5, K2.5; also elsewhere on the board
+12V_TX_bat: K2.1; also elsewhere on the board
/Relay_switch_dsp/out_12v_DSP: K2.3; also elsewhere on the board
/Relay_switch_dsp/out_GND_DSP: K1.3; also elsewhere on the board
GNDD: Q1.1, Q2.1, R1.1, R2.2; also elsewhere on the board
GND_TX_bat: K1.1; also elsewhere on the board
GP2: Q1.2, R1.2; also elsewhere on the board
GP3: Q2.2, R2.1; also elsewhere on the board
unnamed: D1.2 (A), K1.2, Q1.3
unnamed: D2.2 (A), K2.2, Q2.3

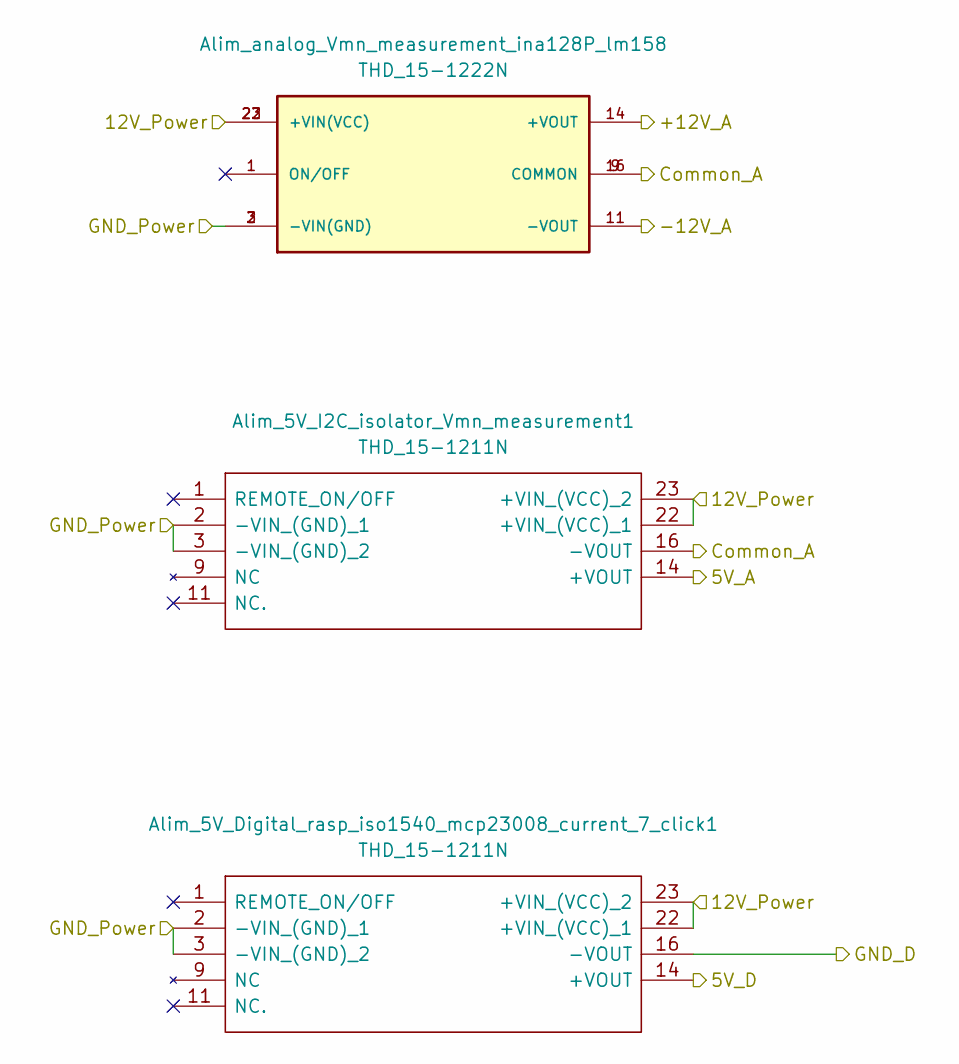
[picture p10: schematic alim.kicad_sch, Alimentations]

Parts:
Alim_5V_Digital_rasp_iso1540_mcp23008_current_7_click1, Alim_5V_I2C_isolator_Vmn_measurement1: THD_15-1211N; THD151211N; Manufacturer_Part_Number THD 15-1211N; Mouser Part Number 495-THD15-1211N
Alim_analog_Vmn_measurement_ina128P_lm158: THD_15-1222N; CONV_THD_15-1222N; PARTREV July 27, 2020

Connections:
5VA: Alim_5V_I2C_isolator_Vmn_measurement1.14 (+VOUT); also elsewhere on the board
5VD: Alim_5V_Digital_rasp_iso1540_mcp23008_c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.14 (+VOUT); also elsewhere on the board
+12V_A: Alim_analog_Vmn_measurement_ina128P_lm1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.14 (+VOUT); also elsewhere on the board
+12V_RX_bat: Alim_5V_Digital_rasp_iso1540_mcp23008_c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.22 (+VIN_(VCC)_1), Alim_5V_Digital_rasp_iso1540_mcp23008_c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.23 (+VIN_(VCC)_2), Alim_5V_I2C_isolator_Vmn_measurement1.22 (+VIN_(VCC)_1), Alim_5V_I2C_isolator_Vmn_measurement1.23 (+VIN_(VCC)_2), Alim_analog_Vmn_measurement_ina128P_lm1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.22 (+VIN(VCC)), Alim_analog_Vmn_measurement_ina128P_lm1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.23 (+VIN(VCC)); also elsewhere on the board
-12V_A: Alim_analog_Vmn_measurement_ina128P_lm1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.11 (-VOUT); also elsewhere on the board
GNDA: Alim_5V_I2C_isolator_Vmn_measurement1.16 (-VOUT), Alim_analog_Vmn_measurement_ina128P_lm1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.9 (COMMON), Alim_analog_Vmn_measurement_ina128P_lm1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.16 (COMMON); also elsewhere on the board
GNDD: Alim_5V_Digital_rasp_iso1540_mcp23008_c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.16 (-VOUT); also elsewhere on the board
GND_RX_bat: Alim_5V_Digital_rasp_iso1540_mcp23008_c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.2 (-VIN_(GND)_1), Alim_5V_Digital_rasp_iso1540_mcp23008_c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.3 (-VIN_(GND)_2), Alim_5V_I2C_isolator_Vmn_measurement1.2 (-VIN_(GND)_1), Alim_5V_I2C_isolator_Vmn_measurement1.3 (-VIN_(GND)_2), Alim_analog_Vmn_measurement_ina128P_lm1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.2 (-VIN(GND)), Alim_analog_Vmn_measurement_ina128P_lm1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.3 (-VIN(GND)); also elsewhere on the board

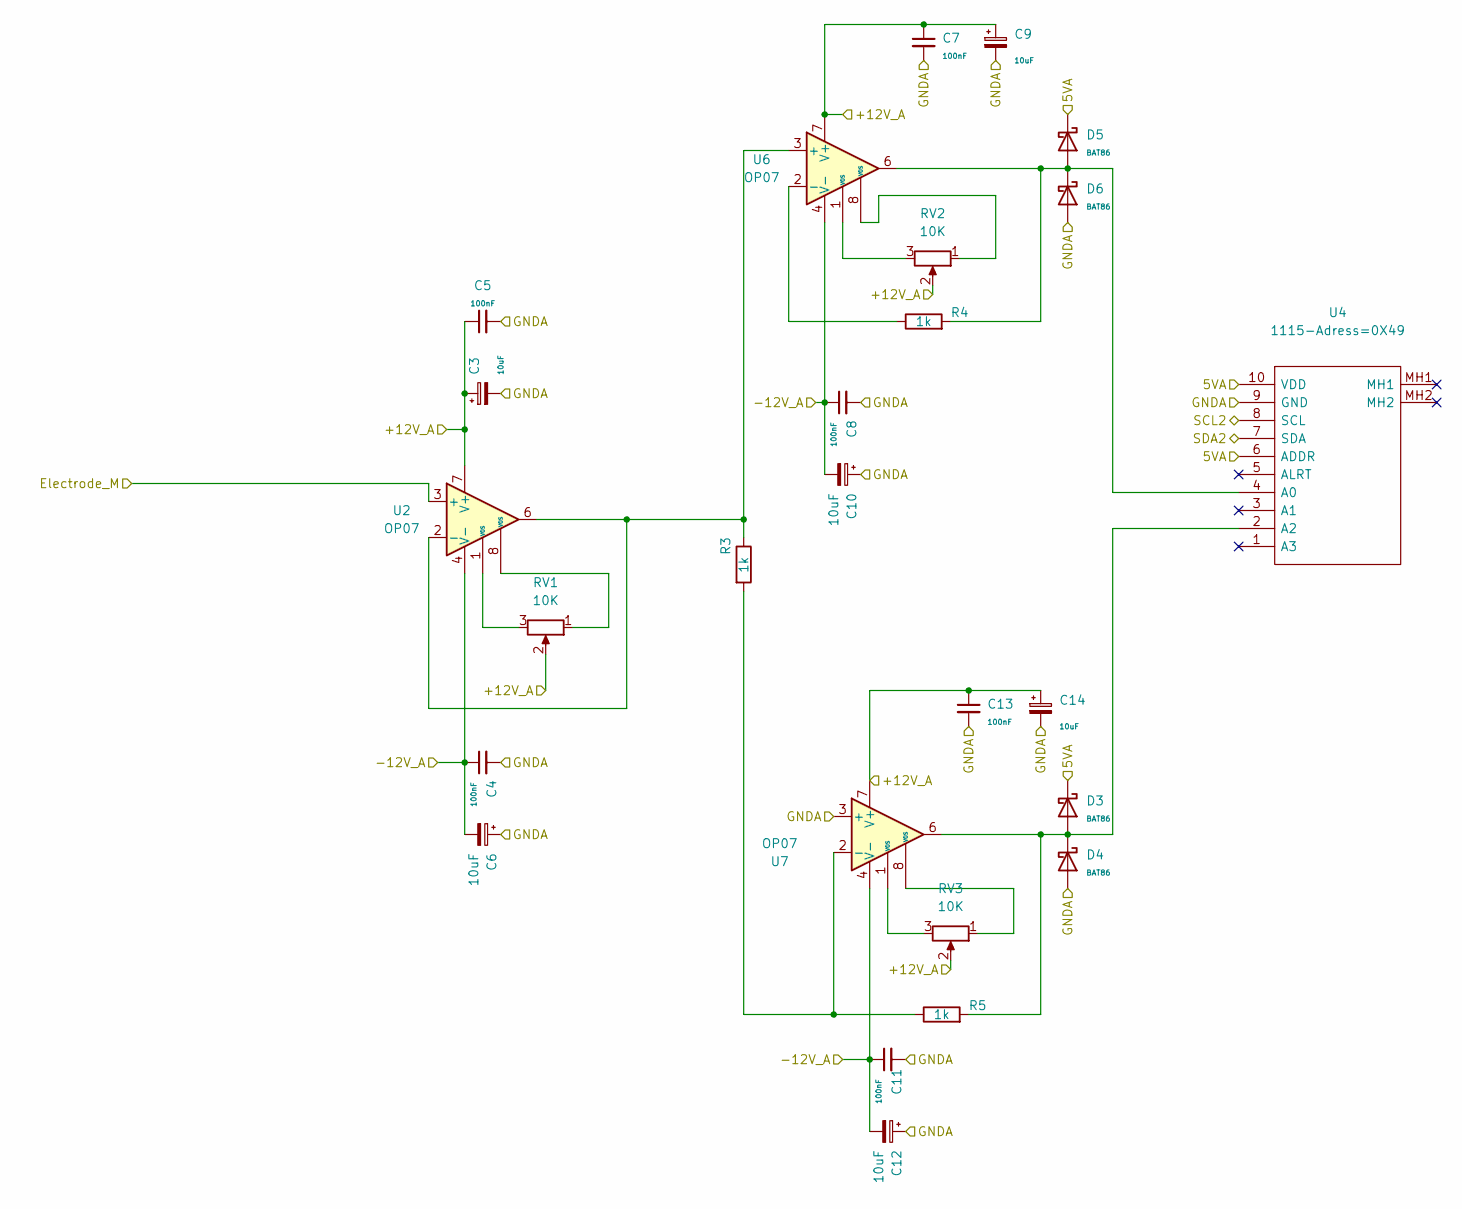
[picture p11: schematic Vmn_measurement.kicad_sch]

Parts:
C3, C6, C9, C10, C12, C14: 10uF; CP_Radial_D6.3mm_P2.50mm
C4, C5, C7, C8, C11, C13: 100nF; C_Disc_D8.0mm_W2.5mm_P5.00mm
D3, D4, D5, D6: BAT86; D_DO-35_SOD27_P7.62mm_Horizontal
R3, R4, R5: 1k; R_Axial_DIN0207_L6.3mm_D2.5mm_P7.62mm_Horizontal
RV1, RV2, RV3: 10K; Potentiometer_Bourns_3296W_Vertical
U2, U6, U7: OP07; DIP-8_W7.62mm
U4: 1115-Adress=0X49; 1085; PARTREV N/A; Mouser Part Number 485-1085

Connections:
5VA: D3.1 (K), D5.1 (K), U4.6 (ADDR), U4.10 (VDD); also elsewhere on the board
+12V_A: C3.1, C5.1, C7.1, C9.1, C13.1, C14.1, RV1.2, RV2.2, RV3.2, U2.7 (V+), U6.7 (V+), U7.7 (V+); also elsewhere on the board
-12V_A: C4.1, C6.2, C8.1, C10.2, C11.1, C12.2, U2.4 (V-), U6.4 (V-), U7.4 (V-); also elsewhere on the board
/Vmn_measurement/Electrode_M: U2.3 (+); also elsewhere on the board
GNDA: C3.2, C4.2, C5.2, C6.1, C7.2, C8.2, C9.2, C10.1, C11.2, C12.1, C13.2, C14.2, D4.2 (A), D6.2 (A), U4.9 (GND), U7.3 (+); also elsewhere on the board
unnamed: D3.2 (A), D4.1 (K), R5.2, U4.2 (A2), U7.6
unnamed: D5.2 (A), D6.1 (K), R4.2, U4.4 (A0), U6.6
unnamed: R3.1, U2.2 (-), U2.6, U6.3 (+)
unnamed: R3.2, R5.1, U7.2 (-)
unnamed: R4.1, U6.2 (-)
unnamed: RV1.1, U2.8 (VOS)
unnamed: RV1.3, U2.1 (VOS)
unnamed: RV2.1, U6.8 (VOS)
unnamed: RV2.3, U6.1 (VOS)
unnamed: RV3.1, U7.8 (VOS)
unnamed: RV3.3, U7.1 (VOS)
SCL2: U4.8 (SCL); also elsewhere on the board
SDA2: U4.7 (SDA); also elsewhere on the board

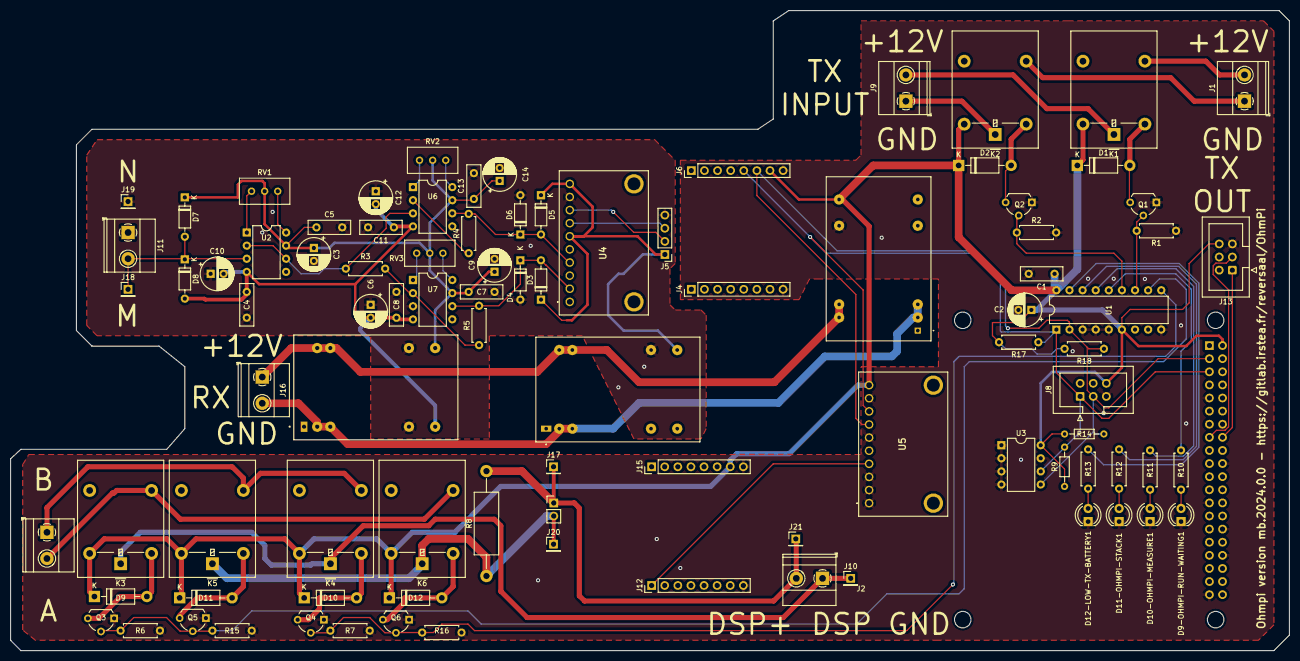
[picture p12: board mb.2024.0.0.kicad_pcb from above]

Board: 2 copper layers, 247.8 x 124.0 mm, 94 parts (1 on the bottom side), 54 nets.

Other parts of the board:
D7, D8: BAT86; D_DO-35_SOD27_P7.62mm_Horizontal
D9-OHMPI-RUN-WAITING1, D10-OHMPI-MEASURE1, D11-OHMPI-STACK1, D12-LOW-TX-BATTERY1: LED; LED_D4.0mm
R10, R11, R12, R13: 330 ohms; R_Axial_DIN0207_L6.3mm_D2.5mm_P7.62mm_Horizontal

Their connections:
+12V_A: D7.1 (K); also elsewhere on the board
-12V_A: D8.2 (A); also elsewhere on the board
/Vmn_measurement/Electrode_M: D7.2 (A), D8.1 (K); also elsewhere on the board
GNDD: D9-OHMPI-RUN-WAITING1.1 (K), D10-OHMPI-MEASURE1.1 (K), D11-OHMPI-STACK1.1 (K), D12-LOW-TX-BATTERY1.1 (K); also elsewhere on the board
GP4: R10.1; also elsewhere on the board
GP5: R11.1; also elsewhere on the board
GP6: R12.1; also elsewhere on the board
GP7: R13.1; also elsewhere on the board
unnamed: D9-OHMPI-RUN-WAITING1.2 (A), R10.2
unnamed: D10-OHMPI-MEASURE1.2 (A), R11.2
unnamed: D11-OHMPI-STACK1.2 (A), R12.2
unnamed: D12-LOW-TX-BATTERY1.2 (A), R13.2

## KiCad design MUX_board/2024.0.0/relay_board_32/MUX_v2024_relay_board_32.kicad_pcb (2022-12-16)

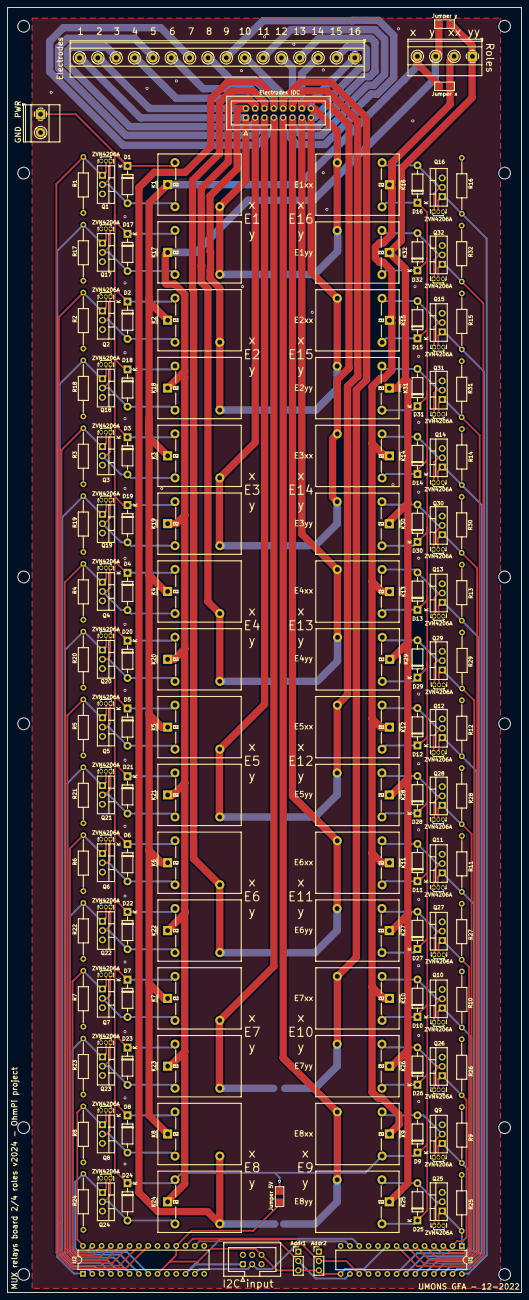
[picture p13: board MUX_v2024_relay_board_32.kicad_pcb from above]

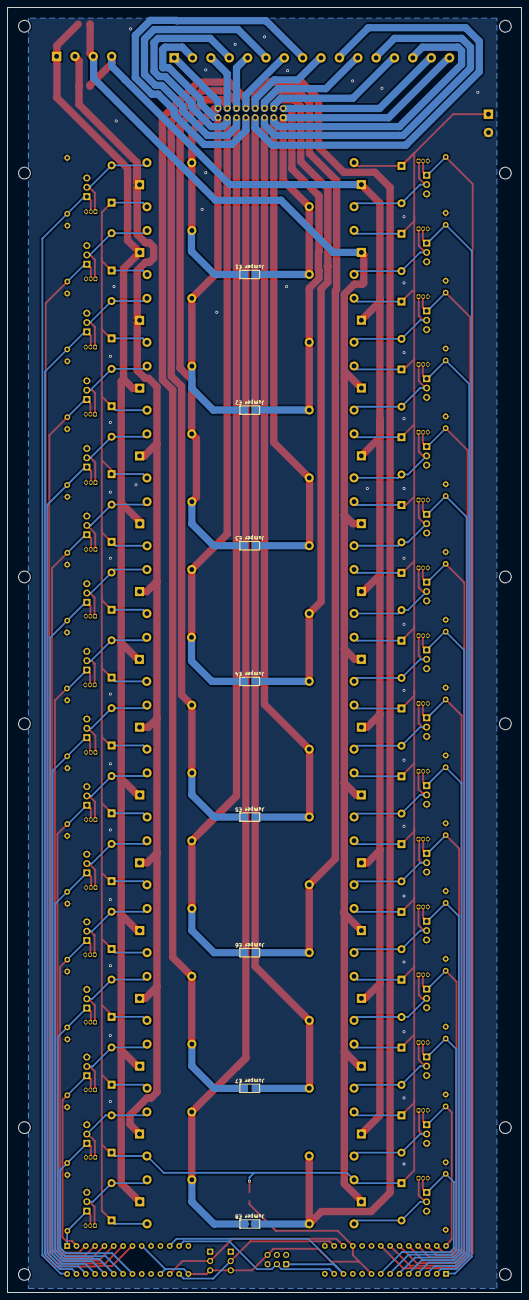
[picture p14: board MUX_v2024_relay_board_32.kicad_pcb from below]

Board: 2 copper layers, 140.0 x 350.0 mm, 180 parts (8 on the bottom side), 91 nets.

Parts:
Addr1: Addr 1; PinHeader_1x03_P2.54mm_Vertical
Addr2: Addr 2; PinHeader_1x03_P2.54mm_Vertical
D1, D2, D3, D4, D5, D6, D7, D8, D9, D10, D11, D12, D13, D14, D15, D16, D17, D18, D19, D20, D21, D22, D23, D24, D25, D26, D27, D28, D29, D30, D31, D32: 1N_E4007; D_DO-41_SOD81_P10.16mm_Horizontal
Electrodes: Screw_Terminal_01x16; TerminalBlock_Phoenix_MKDS-1,5-16_1x16_P5.00mm_Horizontal
Electrodes IDC: Conn_02x08_Odd_Even; IDC-Header_2x08_P2.54mm_Vertical
GND  PWR: Relays Pwr; TerminalBlock_Phoenix_MKDS-1,5-2_1x02_P5.00mm_Horizontal
I2C input: I2C; IDC-Header_2x03_P2.54mm_Vertical
Jumper 5V: SolderJumper_2_Open; Soder_jumper
Jumper E1, Jumper E2, Jumper E3, Jumper E4, Jumper E5, Jumper E6, Jumper E7, Jumper E8: SolderJumper_2_Open; Soder_jumper
Jumper x: SolderJumper_2_Open; Soder_jumper
Jumper y: SolderJumper_2_Open; Soder_jumper
K1, K2, K3, K4, K5, K6, K7, K8, K9, K10, K11, K12, K13, K14, K15, K16, K17, K18, K19, K20, K21, K22, K23, K24, K25, K26, K27, K28, K29, K30, K31, K32: G5LE-1-VD; Relay_SPDT_Omron-G5LE-1-VD
Q1, Q2, Q3, Q4, Q5, Q6, Q7, Q8, Q9, Q10, Q11, Q12, Q13, Q14, Q15, Q16, Q17, Q18, Q19, Q20, Q21, Q22, Q23, Q24, Q25, Q26, Q27, Q28, Q29, Q30, Q31, Q32: STP16NF06L; TO-220-3_Vertical
R1, R2, R3, R4, R5, R6, R7, R8, R9, R10, R11, R12, R13, R14, R15, R16, R17, R18, R19, R20, R21, R22, R23, R24, R25, R26, R27, R28, R29, R30, R31, R32: 100k; R_Axial_DIN0207_L6.3mm_D2.5mm_P15.24mm_Horizontal
U1, U2: MCP23017_SP; DIP-28_W7.62mm
ZVN4206A, ZVN4206A#2, ZVN4206A#3, ZVN4206A#4, ZVN4206A#5, ZVN4206A#6, ZVN4206A#7, ZVN4206A#8, ZVN4206A#9, ZVN4206A#10, ZVN4206A#11, ZVN4206A#12, ZVN4206A#13, ZVN4206A#14, ZVN4206A#15, ZVN4206A#16, ZVN4206A#17, ZVN4206A#18, ZVN4206A#19, ZVN4206A#20, ZVN4206A#21, ZVN4206A#22, ZVN4206A#23, ZVN4206A#24, ZVN4206A#25, ZVN4206A#26, ZVN4206A#27, ZVN4206A#28, ZVN4206A#29, ZVN4206A#30, ZVN4206A#31, ZVN4206A#32: TO-92Flat
x  y  xx yy: Screw_Terminal_01x04; TerminalBlock_Phoenix_MKDS-1,5-4_1x04_P5.00mm_Horizontal

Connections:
12V: D1.1 (K), D2.1 (K), D3.1 (K), D4.1 (K), D5.1 (K), D6.1 (K), D7.1 (K), D8.1 (K), D9.1 (K), D10.1 (K), D11.1 (K), D12.1 (K), D13.1 (K), D14.1 (K), D15.1 (K), D16.1 (K), D17.1 (K), D18.1 (K), D19.1 (K), D20.1 (K), D21.1 (K), D22.1 (K), D23.1 (K), D24.1 (K), D25.1 (K), D26.1 (K), D27.1 (K), D28.1 (K), D29.1 (K), D30.1 (K), D31.1 (K), D32.1 (K), GND PWR.1, Jumper 5V.2 (B), K1.5, K2.5, K3.5, K4.5, K5.5, K6.5, K7.5, K8.5, K9.5, K10.5, K11.5, K12.5, K13.5, K14.5, K15.5, K16.5, K17.5, K18.5, K19.5, K20.5, K21.5, K22.5, K23.5, K24.5, K25.5, K26.5, K27.5, K28.5, K29.5, K30.5, K31.5, K32.5
+5V: Addr1.3 (B), Addr2.3 (B), I2C input.6, Jumper 5V.1 (A), U1.9 (VDD), U1.15 (A0), U1.18 (~RESET), U2.9 (VDD), U2.18 (~RESET)
Addr1: Addr1.2 (C), U1.16 (A1), U2.16 (A1)
Addr2: Addr2.2 (C), U1.17 (A2), U2.17 (A2)
E1x: Q1.1 (G), R1.1, U2.21 (GPA0), ZVN4206A#27.2
E1y: Q17.1 (G), R17.1, U2.1 (GPB0), ZVN4206A#7.2
E2x: Q2.1 (G), R2.1, U2.22 (GPA1), ZVN4206A#6.2
E2y: Q18.1 (G), R18.1, U2.2 (GPB1), ZVN4206A#32.2
E3x: Q3.1 (G), R3.1, U2.23 (GPA2), ZVN4206A#31.2
E3y: Q19.1 (G), R19.1, U2.3 (GPB2), ZVN4206A#9.2
E4x: Q4.1 (G), R4.1, U2.24 (GPA3), ZVN4206A#5.2
E4y: Q20.1 (G), R20.1, U2.4 (GPB3), ZVN4206A#12.2
E5x: Q5.1 (G), R5.1, U2.25 (GPA4), ZVN4206A#26.2
E5y: Q21.1 (G), R21.1, U2.5 (GPB4), ZVN4206A#8.2
E6x: Q6.1 (G), R6.1, U2.26 (GPA5), ZVN4206A#22.2
E6y: Q22.1 (G), R22.1, U2.6 (GPB5), ZVN4206A#11.2
E7x: Q7.1 (G), R7.1, U2.27 (GPA6), ZVN4206A#17.2
E7y: Q23.1 (G), R23.1, U2.7 (GPB6), ZVN4206A#30.2
E8x: Q8.1 (G), R8.1, U2.28 (GPA7), ZVN4206A#2.2
E8y: Q24.1 (G), R24.1, U2.8 (GPB7), ZVN4206A#21.2
E9x: Q9.1 (G), R9.1, U1.21 (GPA0), ZVN4206A#24.2
E9y: Q25.1 (G), R25.1, U1.1 (GPB0), ZVN4206A#28.2
E10x: Q10.1 (G), R10.1, U1.22 (GPA1), ZVN4206A#25.2
E10y: Q26.1 (G), R26.1, U1.2 (GPB1), ZVN4206A#20.2
E11x: Q11.1 (G), R11.1, U1.23 (GPA2), ZVN4206A.2
E11y: Q27.1 (G), R27.1, U1.3 (GPB2), ZVN4206A#10.2
E12x: Q12.1 (G), R12.1, U1.24 (GPA3), ZVN4206A#18.2
E12y: Q28.1 (G), R28.1, U1.4 (GPB3), ZVN4206A#29.2
E13x: Q13.1 (G), R13.1, U1.25 (GPA4), ZVN4206A#13.2
E13y: Q29.1 (G), R29.1, U1.5 (GPB4), ZVN4206A#19.2
E14x: Q14.1 (G), R14.1, U1.26 (GPA5), ZVN4206A#16.2
E14y: Q30.1 (G), R30.1, U1.6 (GPB5), ZVN4206A#14.2
E15x: Q15.1 (G), R15.1, U1.27 (GPA6), ZVN4206A#4.2
E15y: Q31.1 (G), R31.1, U1.7 (GPB6), ZVN4206A#3.2
E16x: Q16.1 (G), R16.1, U1.28 (GPA7), ZVN4206A#15.2
E16y: Q32.1 (G), R32.1, U1.8 (GPB7), ZVN4206A#23.2
Electrode 1: Electrodes.16, Electrodes IDC.1, Jumper E1.1 (A), K1.3, K17.3
Electrode 2: Electrodes.15, Electrodes IDC.2, Jumper E2.1 (A), K2.3, K18.3
Electrode 3: Electrodes.14, Electrodes IDC.3, Jumper E3.1 (A), K3.3, K19.3
Electrode 4: Electrodes.13, Electrodes IDC.4, Jumper E4.1 (A), K4.3, K20.3
Electrode 5: Electrodes.12, Electrodes IDC.5, Jumper E5.1 (A), K5.3, K21.3
Electrode 6: Electrodes.11, Electrodes IDC.6, Jumper E6.1 (A), K6.3, K22.3
Electrode 7: Electrodes.10, Electrodes IDC.7, Jumper E7.1 (A), K7.3, K23.3
Electrode 8: Electrodes.9, Electrodes IDC.8, Jumper E8.1 (A), K8.3, K24.3
Electrode 9: Electrodes.8, Electrodes IDC.9, Jumper E8.2 (B), K9.3, K25.3
Electrode 10: Electrodes.7, Electrodes IDC.10, Jumper E7.2 (B), K10.3, K26.3
Electrode 11: Electrodes.6, Electrodes IDC.11, Jumper E6.2 (B), K11.3, K27.3
Electrode 12: Electrodes.5, Electrodes IDC.12, Jumper E5.2 (B), K12.3, K28.3
Electrode 13: Electrodes.4, Electrodes IDC.13, Jumper E4.2 (B), K13.3, K29.3
Electrode 14: Electrodes.3, Electrodes IDC.14, Jumper E3.2 (B), K14.3, K30.3
Electrode 15: Electrodes.2, Electrodes IDC.15, Jumper E2.2 (B), K15.3, K31.3
Electrode 16: Electrodes.1, Electrodes IDC.16, Jumper E1.2 (B), K16.3, K32.3
GND: Addr1.1 (A), Addr2.1 (A), GND PWR.2, I2C input.5, Q1.3 (S), Q2.3 (S), Q3.3 (S), Q4.3 (S), Q5.3 (S), Q6.3 (S), Q7.3 (S), Q8.3 (S), Q9.3 (S), Q10.3 (S), Q11.3 (S), Q12.3 (S), Q13.3 (S), Q14.3 (S), Q15.3 (S), Q16.3 (S), Q17.3 (S), Q18.3 (S), Q19.3 (S), Q20.3 (S), Q21.3 (S), Q22.3 (S), Q23.3 (S), Q24.3 (S), Q25.3 (S), Q26.3 (S), Q27.3 (S), Q28.3 (S), Q29.3 (S), Q30.3 (S), Q31.3 (S), Q32.3 (S), R1.2, R2.2, R3.2, R4.2, R5.2, R6.2, R7.2, R8.2, R9.2, R10.2, R11.2, R12.2, R13.2, R14.2, R15.2, R16.2, R17.2, R18.2, R19.2, R20.2, R21.2, R22.2, R23.2, R24.2, R25.2, R26.2, R27.2, R28.2, R29.2, R30.2, R31.2, R32.2, U1.10 (VSS), U2.10 (VSS), U2.15 (A0), ZVN4206A.3, ZVN4206A#2.3, ZVN4206A#3.3, ZVN4206A#4.3, ZVN4206A#5.3, ZVN4206A#6.3, ZVN4206A#7.3, ZVN4206A#8.3, ZVN4206A#9.3, ZVN4206A#10.3, ZVN4206A#11.3, ZVN4206A#12.3, ZVN4206A#13.3, ZVN4206A#14.3, ZVN4206A#15.3, ZVN4206A#16.3, ZVN4206A#17.3, ZVN4206A#18.3, ZVN4206A#19.3, ZVN4206A#20.3, ZVN4206A#21.3, ZVN4206A#22.3, ZVN4206A#23.3, ZVN4206A#24.3, ZVN4206A#25.3, ZVN4206A#26.3, ZVN4206A#27.3, ZVN4206A#28.3, ZVN4206A#29.3, ZVN4206A#30.3, ZVN4206A#31.3, ZVN4206A#32.3
unnamed: D1.2 (A), K1.2, Q1.2 (D), ZVN4206A#27.1
unnamed: D2.2 (A), K2.2, Q2.2 (D), ZVN4206A#6.1
unnamed: D3.2 (A), K3.2, Q3.2 (D), ZVN4206A#31.1
unnamed: D4.2 (A), K4.2, Q4.2 (D), ZVN4206A#5.1
unnamed: D5.2 (A), K5.2, Q5.2 (D), ZVN4206A#26.1
unnamed: D6.2 (A), K6.2, Q6.2 (D), ZVN4206A#22.1
unnamed: D7.2 (A), K7.2, Q7.2 (D), ZVN4206A#17.1
unnamed: D8.2 (A), K8.2, Q8.2 (D), ZVN4206A#2.1
unnamed: D9.2 (A), K9.2, Q9.2 (D), ZVN4206A#24.1
unnamed: D10.2 (A), K10.2, Q10.2 (D), ZVN4206A#25.1
unnamed: D11.2 (A), K11.2, Q11.2 (D), ZVN4206A.1
unnamed: D12.2 (A), K12.2, Q12.2 (D), ZVN4206A#18.1
unnamed: D13.2 (A), K13.2, Q13.2 (D), ZVN4206A#13.1
unnamed: D14.2 (A), K14.2, Q14.2 (D), ZVN4206A#16.1
unnamed: D15.2 (A), K15.2, Q15.2 (D), ZVN4206A#4.1
unnamed: D16.2 (A), K16.2, Q16.2 (D), ZVN4206A#15.1
unnamed: D17.2 (A), K17.2, Q17.2 (D), ZVN4206A#7.1
unnamed: D18.2 (A), K18.2, Q18.2 (D), ZVN4206A#32.1
unnamed: D19.2 (A), K19.2, Q19.2 (D), ZVN4206A#9.1
unnamed: D20.2 (A), K20.2, Q20.2 (D), ZVN4206A#12.1
unnamed: D21.2 (A), K21.2, Q21.2 (D), ZVN4206A#8.1
unnamed: D22.2 (A), K22.2, Q22.2 (D), ZVN4206A#11.1
unnamed: D23.2 (A), K23.2, Q23.2 (D), ZVN4206A#30.1
unnamed: D24.2 (A), K24.2, Q24.2 (D), ZVN4206A#21.1
unnamed: D25.2 (A), K25.2, Q25.2 (D), ZVN4206A#28.1
unnamed: D26.2 (A), K26.2, Q26.2 (D), ZVN4206A#20.1
unnamed: D27.2 (A), K27.2, Q27.2 (D), ZVN4206A#10.1
unnamed: D28.2 (A), K28.2, Q28.2 (D), ZVN4206A#29.1
unnamed: D29.2 (A), K29.2, Q29.2 (D), ZVN4206A#19.1
unnamed: D30.2 (A), K30.2, Q30.2 (D), ZVN4206A#14.1
unnamed: D31.2 (A), K31.2, Q31.2 (D), ZVN4206A#3.1
unnamed: D32.2 (A), K32.2, Q32.2 (D), ZVN4206A#23.1
Role x: Jumper x.1 (A), K1.1, K2.1, K3.1, K4.1, K5.1, K6.1, K7.1, K8.1, x y xx yy.4
Role xx: Jumper x.2 (B), K9.1, K10.1, K11.1, K12.1, K13.1, K14.1, K15.1, K16.1, x y xx yy.2
Role y: Jumper y.1 (A), K17.1, K18.1, K19.1, K20.1, K21.1, K22.1, K23.1, K24.1, x y xx yy.3
Role yy: Jumper y.2 (B), K25.1, K26.1, K27.1, K28.1, K29.1, K30.1, K31.1, K32.1, x y xx yy.1
SCL1: I2C input.1, U1.12 (SCK), U2.12 (SCK)
SD1: I2C input.3, U1.13 (SDA), U2.13 (SDA)

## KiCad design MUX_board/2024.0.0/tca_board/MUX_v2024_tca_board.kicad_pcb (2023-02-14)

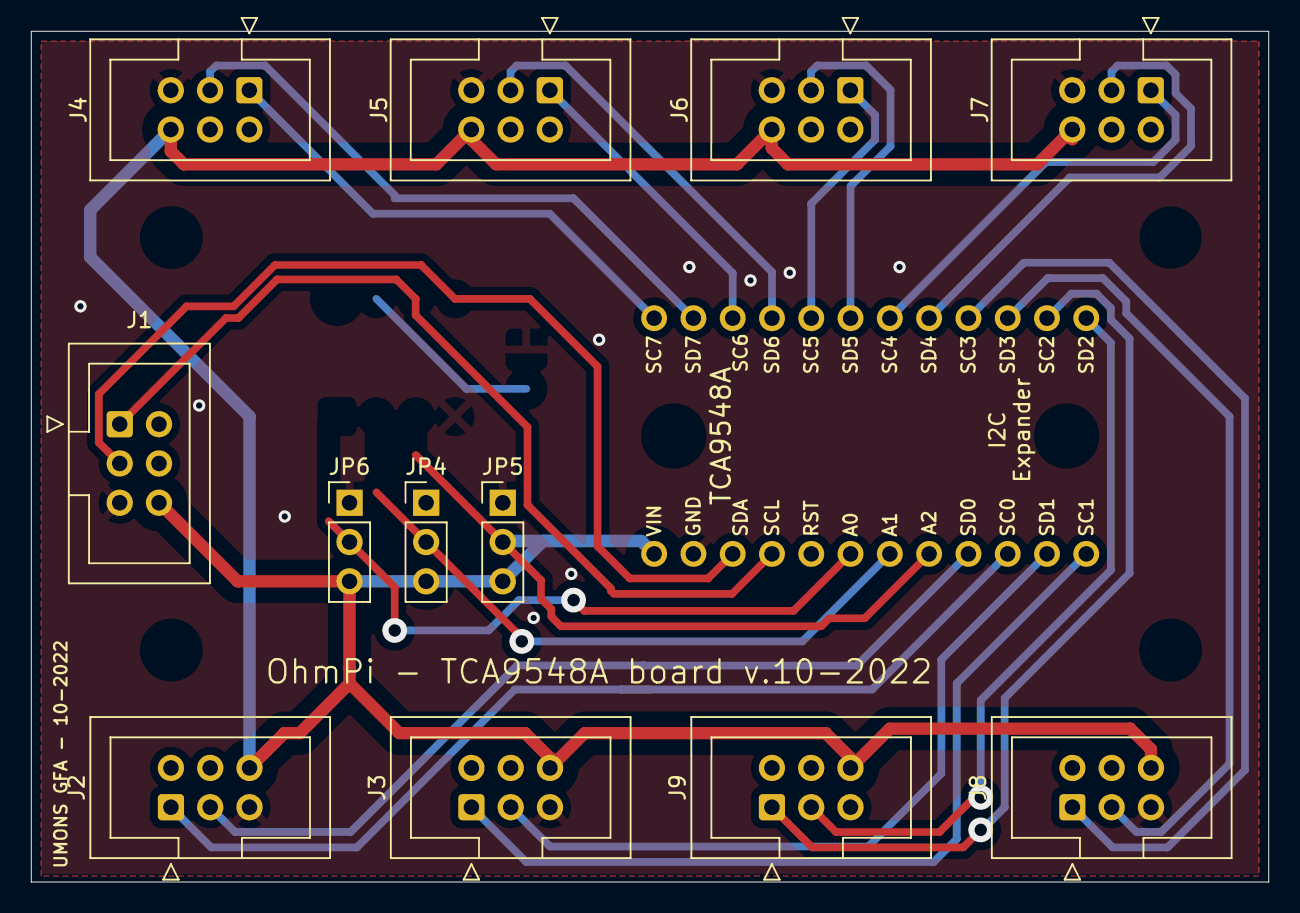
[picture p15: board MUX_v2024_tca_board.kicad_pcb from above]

Board: 2 copper layers, 80.0 x 55.0 mm, 14 parts (0 on the bottom side), 23 nets.

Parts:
J1, J2, J3, J4, J5, J6, J7, J8, J9: I2C; IDC-Header_2x03_P2.54mm_Vertical
JP1, JP3: HEADER-1X12; 1X12_ROUND
JP4: Addr 1; PinHeader_1x03_P2.54mm_Vertical
JP5: Addr 2; PinHeader_1x03_P2.54mm_Vertical
JP6: Addr 0; PinHeader_1x03_P2.54mm_Vertical

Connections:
+5V: J1.6, J2.6, J3.6, J4.6, J5.6, J6.6, J7.6, J8.6, J9.6, JP3.1, JP4.3 (B), JP5.3 (B), JP6.3 (B)
/0SCL: J2.1, JP3.10
/0SDA: J2.3, JP3.9
/1SCL: J3.1, JP3.12
/1SDA: J3.3, JP3.11
/2SCL: J9.1, JP1.2
/2SDA: J9.3, JP1.1
/3SCL: J8.1, JP1.4
/3SDA: J8.3, JP1.3
/4SCL: J7.1, JP1.6
/4SDA: J7.3, JP1.5
/5SCL: J6.1, JP1.8
/5SDA: J6.3, JP1.7
/6SCL: J5.1, JP1.10
/6SDA: J5.3, JP1.9
/7SCL: J4.1, JP1.12
/7SDA: J4.3, JP1.11
/A0: JP3.6, JP6.2 (C)
/A1: JP3.7, JP4.2 (C)
/A2: JP3.8, JP5.2 (C)
/INPUTSCL: J1.1, JP3.4
/INPUTSDA: J1.3, JP3.3
GNDD: J1.5, J2.5, J3.5, J4.5, J5.5, J6.5, J7.5, J8.5, J9.5, JP3.2, JP4.1 (A), JP5.1 (A), JP6.1 (A)

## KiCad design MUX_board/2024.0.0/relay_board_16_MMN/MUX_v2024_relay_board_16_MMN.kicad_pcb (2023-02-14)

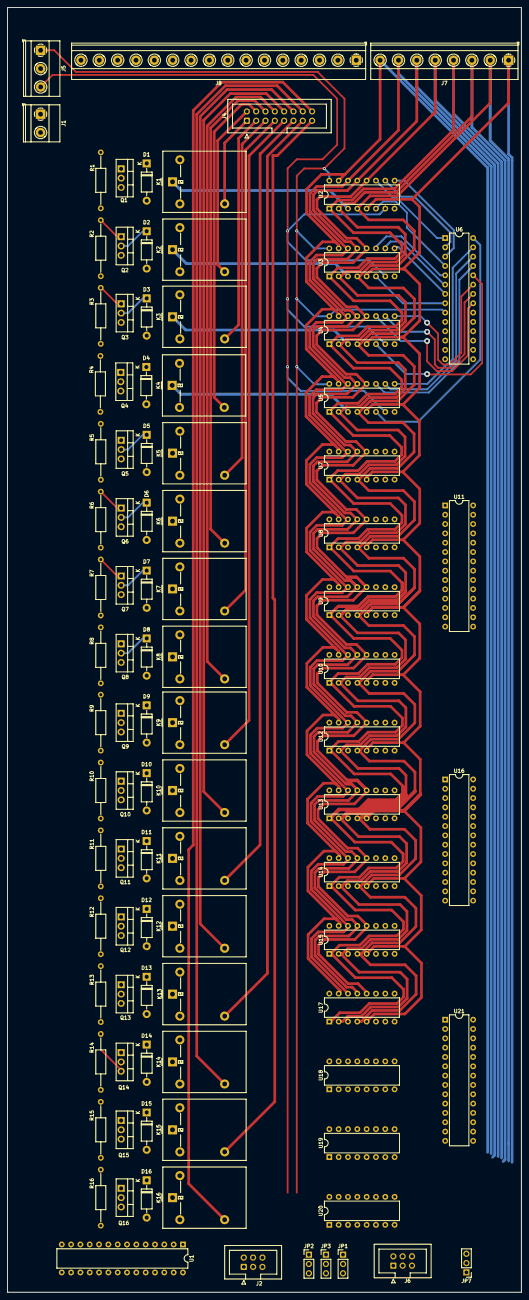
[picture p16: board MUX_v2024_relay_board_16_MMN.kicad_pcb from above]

Board: 2 copper layers, 140.0 x 350.1 mm, 96 parts (0 on the bottom side), 149 nets.

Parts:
D1, D2, D3, D4, D5, D6, D7, D8, D9, D10, D11, D12, D13, D14, D15, D16: 1N_E4007; D_DO-41_SOD81_P10.16mm_Horizontal
J1: Relays Pwr; TerminalBlock_Phoenix_MKDS-1,5-2_1x02_P5.00mm_Horizontal
J2, J6: I2C; IDC-Header_2x03_P2.54mm_Vertical
J4: Conn_02x08_Odd_Even; IDC-Header_2x08_P2.54mm_Vertical
J5: Screw_Terminal_01x03; TerminalBlock_Phoenix_MKDS-1,5-3_1x03_P5.00mm_Horizontal
J7: Screw_Terminal_01x08; TerminalBlock_Phoenix_MKDS-1,5-8_1x08_P5.00mm_Horizontal
J8: Screw_Terminal_01x16; TerminalBlock_Phoenix_MKDS-1,5-16_1x16_P5.00mm_Horizontal
JP1, JP7: Addr 2; PinHeader_1x03_P2.54mm_Vertical
JP2: Addr 1; PinHeader_1x03_P2.54mm_Vertical
JP3: Addr 0; PinHeader_1x03_P2.54mm_Vertical
K1, K2, K3, K4, K5, K6, K7, K8, K9, K10, K11, K12, K13, K14, K15, K16: G5LE-1-VD; Relay_SPDT_Omron-G5LE-1-VD
Q1, Q2, Q3, Q4, Q5, Q6, Q7, Q8, Q9, Q10, Q11, Q12, Q13, Q14, Q15, Q16: STP16NF06L; TO-220-3_Vertical
R1, R2, R3, R4, R5, R6, R7, R8, R9, R10, R11, R12, R13, R14, R15, R16: 100k; R_Axial_DIN0207_L6.3mm_D2.5mm_P15.24mm_Horizontal
U1, U6, U11, U16, U21: MCP23017_SP; DIP-28_W7.62mm
U2, U3, U4, U5, U7, U8, U9, U10, U12, U13, U14, U15, U17, U18, U19, U20: 74HC4051; DIP-16_W7.62mm

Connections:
12V: D1.1 (K), D2.1 (K), D3.1 (K), D4.1 (K), D5.1 (K), D6.1 (K), D7.1 (K), D8.1 (K), D9.1 (K), D10.1 (K), D11.1 (K), D12.1 (K), D13.1 (K), D14.1 (K), D15.1 (K), D16.1 (K), J1.1, K1.5, K2.5, K3.5, K4.5, K5.5, K6.5, K7.5, K8.5, K9.5, K10.5, K11.5, K12.5, K13.5, K14.5, K15.5, K16.5
+5V: J2.6, JP1.3 (B), JP2.3 (B), JP3.3 (B), U1.9 (VDD)
+5VA: J5.1, JP7.3 (B), U2.16 (VCC), U3.16 (VCC), U4.16 (VCC), U5.16 (VCC), U6.9 (VDD), U7.16 (VCC), U8.16 (VCC), U9.16 (VCC), U10.16 (VCC), U11.9 (VDD), U11.15 (A0), U12.16 (VCC), U13.16 (VCC), U14.16 (VCC), U15.16 (VCC), U16.9 (VDD), U16.16 (A1), U17.16 (VCC), U18.16 (VCC), U19.16 (VCC), U20.16 (VCC), U21.9 (VDD), U21.15 (A0), U21.16 (A1)
-5VA: J5.3, U2.7 (VEE), U3.7 (VEE), U4.7 (VEE), U5.7 (VEE), U7.7 (VEE), U8.7 (VEE), U9.7 (VEE), U10.7 (VEE), U12.7 (VEE), U13.7 (VEE), U14.7 (VEE), U15.7 (VEE), U17.7 (VEE), U18.7 (VEE), U19.7 (VEE), U20.7 (VEE)
Addr0: JP3.2 (C), U1.15 (A0)
Addr1: JP2.2 (C), U1.16 (A1)
Addr2: JP1.2 (C), JP7.2 (C), U1.17 (A2), U6.17 (A2), U11.17 (A2), U16.17 (A2), U21.17 (A2)
E1: Q1.1 (G), R1.1, U1.1 (GPB0)
E2: Q2.1 (G), R2.1, U1.2 (GPB1)
E3: Q3.1 (G), R3.1, U1.3 (GPB2)
E4: Q4.1 (G), R4.1, U1.4 (GPB3)
E5: Q5.1 (G), R5.1, U1.5 (GPB4)
E6: Q6.1 (G), R6.1, U1.6 (GPB5)
E7: Q7.1 (G), R7.1, U1.7 (GPB6)
E8: Q8.1 (G), R8.1, U1.8 (GPB7)
E9: Q9.1 (G), R9.1, U1.21 (GPA0)
E10: Q10.1 (G), R10.1, U1.22 (GPA1)
E11: Q11.1 (G), R11.1, U1.23 (GPA2)
E12: Q12.1 (G), R12.1, U1.24 (GPA3)
E13: Q13.1 (G), R13.1, U1.25 (GPA4)
E14: Q14.1 (G), R14.1, U1.26 (GPA5)
E15: Q15.1 (G), R15.1, U1.27 (GPA6)
E16: Q16.1 (G), R16.1, U1.28 (GPA7)
Electrode 1: J4.1, J8.16, K1.3
Electrode 2: J4.2, J8.15, K2.3
Electrode 3: J4.3, J8.14, K3.3
Electrode 4: J4.4, J8.13, K4.3
Electrode 5: J4.5, J8.12, K5.3
Electrode 6: J4.6, J8.11, K6.3
Electrode 7: J4.7, J8.10, K7.3
Electrode 8: J4.8, J8.9, K8.3
Electrode 9: J4.9, J8.8, K9.3
Electrode 10: J4.10, J8.7, K10.3
Electrode 11: J4.11, J8.6, K11.3
Electrode 12: J4.12, J8.5, K12.3
Electrode 13: J4.13, J8.4, K13.3
Electrode 14: J4.14, J8.3, K14.3
Electrode 15: J4.15, J8.2, K15.3
Electrode 16: J4.16, J8.1, K16.3
Enable_MUX1: U2.6 (~E), U6.4 (GPB3)
Enable_MUX2: U3.6 (~E), U6.8 (GPB7)
Enable_MUX3: U4.6 (~E), U6.24 (GPA3)
Enable_MUX4: U5.6 (~E), U6.28 (GPA7)
Enable_MUX5: U7.6 (~E), U11.4 (GPB3)
Enable_MUX6: U8.6 (~E), U11.8 (GPB7)
Enable_MUX7: U9.6 (~E), U11.24 (GPA3)
Enable_MUX8: U10.6 (~E), U11.28 (GPA7)
Enable_MUX9: U12.6 (~E), U16.4 (GPB3)
Enable_MUX10: U13.6 (~E), U16.8 (GPB7)
Enable_MUX11: U14.6 (~E), U16.24 (GPA3)
Enable_MUX12: U15.6 (~E), U16.28 (GPA7)
Enable_MUX13: U17.6 (~E), U21.4 (GPB3)
Enable_MUX14: U18.6 (~E), U21.8 (GPB7)
Enable_MUX15: U19.6 (~E), U21.24 (GPA3)
Enable_MUX16: U20.6 (~E), U21.28 (GPA7)
GND: J1.2, J2.5, JP1.1 (A), JP2.1 (A), JP3.1 (A), Q1.3 (S), Q2.3 (S), Q3.3 (S), Q4.3 (S), Q5.3 (S), Q6.3 (S), Q7.3 (S), Q8.3 (S), Q9.3 (S), Q10.3 (S), Q11.3 (S), Q12.3 (S), Q13.3 (S), Q14.3 (S), Q15.3 (S), Q16.3 (S), R1.2, R2.2, R3.2, R4.2, R5.2, R6.2, R7.2, R8.2, R9.2, R10.2, R11.2, R12.2, R13.2, R14.2, R15.2, R16.2, U1.10 (VSS), U1.18 (~RESET)
GNDA: J5.2, JP7.1 (A), U2.8 (GND), U3.8 (GND), U4.8 (GND), U5.8 (GND), U6.10 (VSS), U6.15 (A0), U6.16 (A1), U6.18 (~RESET), U7.8 (GND), U8.8 (GND), U9.8 (GND), U10.8 (GND), U11.10 (VSS), U11.16 (A1), U11.18 (~RESET), U12.8 (GND), U13.8 (GND), U14.8 (GND), U15.8 (GND), U16.10 (VSS), U16.15 (A0), U16.18 (~RESET), U17.8 (GND), U18.8 (GND), U19.8 (GND), U20.8 (GND), U21.10 (VSS), U21.18 (~RESET)
unnamed: D1.2 (A), K1.2, Q1.2 (D)
unnamed: D2.2 (A), K2.2, Q2.2 (D)
unnamed: D3.2 (A), K3.2, Q3.2 (D)
unnamed: D4.2 (A), K4.2, Q4.2 (D)
unnamed: D5.2 (A), K5.2, Q5.2 (D)
unnamed: D6.2 (A), K6.2, Q6.2 (D)
unnamed: D7.2 (A), K7.2, Q7.2 (D)
unnamed: D8.2 (A), K8.2, Q8.2 (D)
unnamed: D9.2 (A), K9.2, Q9.2 (D)
unnamed: D10.2 (A), K10.2, Q10.2 (D)
unnamed: D11.2 (A), K11.2, Q11.2 (D)
unnamed: D12.2 (A), K12.2, Q12.2 (D)
unnamed: D13.2 (A), K13.2, Q13.2 (D)
unnamed: D14.2 (A), K14.2, Q14.2 (D)
unnamed: D15.2 (A), K15.2, Q15.2 (D)
unnamed: D16.2 (A), K16.2, Q16.2 (D)
Role M1x: J7.8, U2.15 (A2), U3.15 (A2), U4.15 (A2), U5.15 (A2), U7.15 (A2), U8.15 (A2), U9.15 (A2), U10.15 (A2), U12.15 (A2), U13.15 (A2), U14.15 (A2), U15.15 (A2), U17.15 (A2), U18.15 (A2), U19.15 (A2), U20.15 (A2)
Role M1y: J7.7, U2.14 (A1), U3.14 (A1), U4.14 (A1), U5.14 (A1), U7.14 (A1), U8.14 (A1), U9.14 (A1), U10.14 (A1), U12.14 (A1), U13.14 (A1), U14.14 (A1), U15.14 (A1), U17.14 (A1), U18.14 (A1), U19.14 (A1), U20.14 (A1)
Role M2x: J7.6, U2.13 (A0), U3.13 (A0), U4.13 (A0), U5.13 (A0), U7.13 (A0), U8.13 (A0), U9.13 (A0), U10.13 (A0), U12.13 (A0), U13.13 (A0), U14.13 (A0), U15.13 (A0), U17.13 (A0), U18.13 (A0), U19.13 (A0), U20.13 (A0)
Role M3y: J7.5, U2.12 (A3), U3.12 (A3), U4.12 (A3), U5.12 (A3), U7.12 (A3), U8.12 (A3), U9.12 (A3), U10.12 (A3), U12.12 (A3), U13.12 (A3), U14.12 (A3), U15.12 (A3), U17.12 (A3), U18.12 (A3), U19.12 (A3), U20.12 (A3)
Role MN_E1: K1.1, U2.3 (A)
Role MN_E2: K2.1, U3.3 (A)
Role MN_E3: K3.1, U4.3 (A)
Role MN_E4: K4.1, U5.3 (A)
Role MN_E5: K5.1, U7.3 (A)
Role MN_E6: K6.1, U8.3 (A)
Role MN_E7: K7.1, U9.3 (A)
Role MN_E8: K8.1, U10.3 (A)
Role MN_E9: K9.1, U12.3 (A)
Role MN_E10: K10.1, U13.3 (A)
Role MN_E11: K11.1, U14.3 (A)
Role MN_E12: K12.1, U15.3 (A)
Role MN_E13: K13.1, U17.3 (A)
Role MN_E14: K14.1, U18.3 (A)
Role MN_E15: K15.1, U19.3 (A)
Role MN_E16: K16.1, U20.3 (A)
Role N1: J7.4, U2.1 (A4), U3.1 (A4), U4.1 (A4), U5.1 (A4), U7.1 (A4), U8.1 (A4), U9.1 (A4), U10.1 (A4), U12.1 (A4), U13.1 (A4), U14.1 (A4), U15.1 (A4), U17.1 (A4), U18.1 (A4), U19.1 (A4), U20.1 (A4)
Role N2: J7.3, U2.2 (A6), U3.2 (A6), U4.2 (A6), U5.2 (A6), U7.2 (A6), U8.2 (A6), U9.2 (A6), U10.2 (A6), U12.2 (A6), U13.2 (A6), U14.2 (A6), U15.2 (A6), U17.2 (A6), U18.2 (A6), U19.2 (A6), U20.2 (A6)
Role N3: J7.2, U2.4 (A7), U3.4 (A7), U4.4 (A7), U5.4 (A7), U7.4 (A7), U8.4 (A7), U9.4 (A7), U10.4 (A7), U12.4 (A7), U13.4 (A7), U14.4 (A7), U15.4 (A7), U17.4 (A7), U18.4 (A7), U19.4 (A7), U20.4 (A7)
Role N4: J7.1, U2.5 (A5), U3.5 (A5), U4.5 (A5), U5.5 (A5), U7.5 (A5), U8.5 (A5), U9.5 (A5), U10.5 (A5), U12.5 (A5), U13.5 (A5), U14.5 (A5), U15.5 (A5), U17.5 (A5), U18.5 (A5), U19.5 (A5), U20.5 (A5)
S0_MUX1: U2.11 (S0), U6.1 (GPB0)
S0_MUX2: U3.11 (S0), U6.5 (GPB4)
S0_MUX3: U4.11 (S0), U6.21 (GPA0)
S0_MUX4: U5.11 (S0), U6.25 (GPA4)
S0_MUX5: U7.11 (S0), U11.1 (GPB0)
S0_MUX6: U8.11 (S0), U11.5 (GPB4)
S0_MUX7: U9.11 (S0), U11.21 (GPA0)
S0_MUX8: U10.11 (S0), U11.25 (GPA4)
S0_MUX9: U12.11 (S0), U16.1 (GPB0)
S0_MUX10: U13.11 (S0), U16.5 (GPB4)
S0_MUX11: U14.11 (S0), U16.21 (GPA0)
S0_MUX12: U15.11 (S0), U16.25 (GPA4)
S0_MUX13: U17.11 (S0), U21.1 (GPB0)
S0_MUX14: U18.11 (S0), U21.5 (GPB4)
S0_MUX15: U19.11 (S0), U21.21 (GPA0)
S0_MUX16: U20.11 (S0), U21.25 (GPA4)
S1_MUX1: U2.10 (S1), U6.2 (GPB1)
S1_MUX2: U3.10 (S1), U6.6 (GPB5)
S1_MUX3: U4.10 (S1), U6.22 (GPA1)
S1_MUX4: U5.10 (S1), U6.26 (GPA5)
S1_MUX5: U7.10 (S1), U11.2 (GPB1)
S1_MUX6: U8.10 (S1), U11.6 (GPB5)
S1_MUX7: U9.10 (S1), U11.22 (GPA1)
S1_MUX8: U10.10 (S1), U11.26 (GPA5)
S1_MUX9: U12.10 (S1), U16.2 (GPB1)
S1_MUX10: U13.10 (S1), U16.6 (GPB5)
S1_MUX11: U14.10 (S1), U16.22 (GPA1)
S1_MUX12: U15.10 (S1), U16.26 (GPA5)
S1_MUX13: U17.10 (S1), U21.2 (GPB1)
S1_MUX14: U18.10 (S1), U21.6 (GPB5)
S1_MUX15: U19.10 (S1), U21.22 (GPA1)
S1_MUX16: U20.10 (S1), U21.26 (GPA5)
S2_MUX1: U2.9 (S2), U6.3 (GPB2)
S2_MUX2: U3.9 (S2), U6.7 (GPB6)
S2_MUX3: U4.9 (S2), U6.23 (GPA2)
S2_MUX4: U5.9 (S2), U6.27 (GPA6)
S2_MUX5: U7.9 (S2), U11.3 (GPB2)
S2_MUX6: U8.9 (S2), U11.7 (GPB6)
S2_MUX7: U9.9 (S2), U11.23 (GPA2)
S2_MUX8: U10.9 (S2), U11.27 (GPA6)
S2_MUX9: U12.9 (S2), U16.3 (GPB2)
S2_MUX10: U13.9 (S2), U16.7 (GPB6)
S2_MUX11: U14.9 (S2), U16.23 (GPA2)
S2_MUX12: U15.9 (S2), U16.27 (GPA6)
S2_MUX13: U17.9 (S2), U21.3 (GPB2)
S2_MUX14: U18.9 (S2), U21.7 (GPB6)
S2_MUX15: U19.9 (S2), U21.23 (GPA2)
S2_MUX16: U20.9 (S2), U21.27 (GPA6)
SCL1: J2.1, U1.12 (SCK)
SCL2: J6.1, U6.12 (SCK), U11.12 (SCK), U16.12 (SCK), U21.12 (SCK)
SD1: J2.3, U1.13 (SDA)
SDA_2: J6.3, U6.13 (SDA), U11.13 (SDA), U16.13 (SDA), U21.13 (SDA)

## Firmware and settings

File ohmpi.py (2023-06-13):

# -*- coding: utf-8 -*-
"""
created on January 6, 2020.
Updates may 2023.
Hardware: Licensed under CERN-OHL-S v2 or any later version
Software: Licensed under the GNU General Public License v3.0
Ohmpi.py is a program to control a low-cost and open hardware resistivity meter OhmPi that has been developed by
Rémi CLEMENT (INRAE), Vivien DUBOIS (INRAE), Hélène GUYARD (IGE), Nicolas FORQUET (INRAE), Yannick FARGIER (IFSTTAR)
Olivier KAUFMANN (UMONS), Arnaud WATLET (UMONS) and Guillaume BLANCHY (FNRS/ULiege).
"""

import os
from utils import get_platform
import json
import warnings
from copy import deepcopy
import numpy as np
import csv
import time
import shutil
from datetime import datetime
from termcolor import colored
import threading
from logging_setup import setup_loggers
from config import MQTT_CONTROL_CONFIG, OHMPI_CONFIG, EXEC_LOGGING_CONFIG
from logging import DEBUG
from plots import *

# finish import (done only when class is instantiated as some libs are only available on arm64 platform)
try:
    import board  # noqa
    import busio  # noqa
    import adafruit_tca9548a  # noqa
    import adafruit_ads1x15.ads1115 as ads  # noqa
    from adafruit_ads1x15.ads1x15 import Mode
    from adafruit_ads1x15.analog_in import AnalogIn  # noqa
    from adafruit_ads1x15.ads1x15 import Mode
    from adafruit_mcp230xx.mcp23008 import MCP23008  # noqa
    from adafruit_mcp230xx.mcp23017 import MCP23017  # noqa
    from adafruit_extended_bus import ExtendedI2C
    import digitalio  # noqa
    from digitalio import Direction  # noqa
    from gpiozero import CPUTemperature  # noqa
    import minimalmodbus  # noqa

    arm64_imports = True
except ImportError as error:
    if EXEC_LOGGING_CONFIG['logging_level'] == DEBUG:
        print(colored(f'Import error: {error}', 'yellow'))
    arm64_imports = False
except Exception as error:
    print(colored(f'Unexpected error: {error}', 'red'))
    arm64_imports = None

class OhmPi(object):
    """ OhmPi class.
    """

    def __init__(self, settings=None, sequence=None, use_mux=False, mqtt=True, onpi=None, idps=False):
        """Constructs the ohmpi object

        Parameters
        ----------
        settings:

        sequence:

        use_mux:
            if True use the multiplexor to select active electrodes
        mqtt: bool, defaut: True
            if True publish on mqtt topics while logging, otherwise use other loggers only
        onpi: bool,None default: None
            if None, the platform on which the class is instantiated is determined to set on_pi to either True or False.
            if False the behaviour of an ohmpi will be partially emulated and return random data.
        idps:
            if true uses the DPS
        """

        if onpi is None:
            _, onpi = get_platform()

        self._sequence = sequence
        self.nb_samples = 0
        self.use_mux = use_mux
        self.on_pi = onpi  # True if run from the RaspberryPi with the hardware, otherwise False for random data
        self.status = 'idle'  # either running or idle
        self.thread = None  # contains the handle for the thread taking the measurement

        # set loggers
        config_exec_logger, _, config_data_logger, _, _, msg = setup_loggers(mqtt=mqtt)  # TODO: add SOH
        self.data_logger = config_data_logger
        self.exec_logger = config_exec_logger
        self.soh_logger = None  # TODO: Implement the SOH logger
        print(msg)

        # read in hardware parameters (config.py)
        self._read_hardware_config()

        # default acquisition settings
        self.settings = {
            'injection_duration': 0.2,
            'nb_meas': 1,
            'sequence_delay': 1,
            'nb_stack': 1,
            'sampling_interval': 2,
            'export_dir': 'data',
            'export_name': 'measurement.csv',
            'tx_volt': 5,
            'duty_cycle': 0.5,
            'strategy': 'constant'
        }
        # read in acquisition settings
        if settings is not None:
            self.update_settings(settings)

        self.exec_logger.debug('Initialized with settings:' + str(self.settings))

        # read quadrupole sequence
        if sequence is not None:
            self.load_sequence(sequence)

        self.idps = idps  # flag to use dps for injection or not

        # connect to components on the OhmPi board
        if self.on_pi:
            # activation of I2C protocol
            self.i2c = busio.I2C(board.SCL, board.SDA)  # noqa
            if self.i2c_mux_address == 2:
                self.i2c_mux = self.i2c
            else:
                self.i2c_mux = ExtendedI2C(self.i2c_mux_address)

            # I2C connexion to MCP23008, for current injection
            self.mcp_board = MCP23008(self.i2c, address=self.mcp_board_address)
            self.pin4 = self.mcp_board.get_pin(4) # Ohmpi_run
            self.pin4.direction = Direction.OUTPUT
            self.pin4.value = True

            # ADS1115 for current measurement (AB)
            self.ads_current_address = 0x48
            self.ads_current = ads.ADS1115(self.i2c, gain=2 / 3, data_rate=860, address=self.ads_current_address)

            # ADS1115 for voltage measurement (MN)
            self.ads_voltage_address = 0x49
            self.ads_voltage = ads.ADS1115(self.i2c, gain=2 / 3, data_rate=860, address=self.ads_voltage_address)

            # current injection module
            if self.idps:
                #self.switch_dps('on')
                self.pin2 = self.mcp_board.get_pin(2) # dsp +
                self.pin2.direction = Direction.OUTPUT
                self.pin2.value = True
                self.pin3 = self.mcp_board.get_pin(3) # dsp -
                self.pin3.direction = Direction.OUTPUT
                self.pin3.value = True
                time.sleep(4)
                self.DPS = minimalmodbus.Instrument(port='/dev/ttyUSB0', slaveaddress=1)  # port name, address (decimal)
                self.DPS.serial.baudrate = 9600  # Baud rate 9600 as listed in doc
                self.DPS.serial.bytesize = 8  #
                self.DPS.serial.timeout = 1  # greater than 0.5 for it to work
                self.DPS.debug = False  #
                self.DPS.serial.parity = 'N'  # No parity
                self.DPS.mode = minimalmodbus.MODE_RTU  # RTU mode
                self.DPS.write_register(0x0001, 200, 0)  # max current allowed (100 mA for relays)
                # (last number) 0 is for mA, 3 is for A
                #self.soh_logger.debug(f'Battery voltage: {self.DPS.read_register(0x05,2 ):.3f}') TODO: SOH logger
                batt_level = self._read_battery_level()
                msg = f'Battery voltage: {batt_level:.3f}'
                if batt_level < 12:
                    print(colored(f'\u2611 {msg}', 'red'))
                else:
                    print(colored(f'\u2611 {msg}', 'green'))
                self.switch_dps('off')


            # injection courant and measure (TODO check if it works, otherwise back in run_measurement())
            self.pin0 = self.mcp_board.get_pin(0)
            self.pin0.direction = Direction.OUTPUT
            self.pin0.value = False
            self.pin1 = self.mcp_board.get_pin(1)
            self.pin1.direction = Direction.OUTPUT
            self.pin1.value = False

        # set controller
        self.mqtt = mqtt
        self.cmd_id = None
        if self.mqtt:
            import paho.mqtt.client as mqtt_client

            self.exec_logger.debug(f"Connecting to control topic {MQTT_CONTROL_CONFIG['ctrl_topic']}"
                                   f" on {MQTT_CONTROL_CONFIG['hostname']} broker")

            def connect_mqtt() -> mqtt_client:
                def on_connect(mqttclient, userdata, flags, rc):
                    if rc == 0:
                        self.exec_logger.debug(f"Successfully connected to control broker:"
                                               f" {MQTT_CONTROL_CONFIG['hostname']}")
                    else:
                        self.exec_logger.warning(f'Failed to connect to control broker. Return code : {rc}')

                client = mqtt_client.Client(f"ohmpi_{OHMPI_CONFIG['id']}_listener", clean_session=False)
                client.username_pw_set(MQTT_CONTROL_CONFIG['auth'].get('username'),
                                       MQTT_CONTROL_CONFIG['auth']['password'])
                client.on_connect = on_connect
                client.connect(MQTT_CONTROL_CONFIG['hostname'], MQTT_CONTROL_CONFIG['port'])
                return client

            try:
                self.exec_logger.debug(f"Connecting to control broker: {MQTT_CONTROL_CONFIG['hostname']}")
                self.controller = connect_mqtt()
            except Exception as e:
                self.exec_logger.debug(f'Unable to connect control broker: {e}')
                self.controller = None
            if self.controller is not None:
                self.exec_logger.debug(f"Subscribing to control topic {MQTT_CONTROL_CONFIG['ctrl_topic']}")
                try:
                    self.controller.subscribe(MQTT_CONTROL_CONFIG['ctrl_topic'], MQTT_CONTROL_CONFIG['qos'])

                    msg = f"Subscribed to control topic {MQTT_CONTROL_CONFIG['ctrl_topic']}" \
                          f" on {MQTT_CONTROL_CONFIG['hostname']} broker"
                    self.exec_logger.debug(msg)
                    print(colored(f'\u2611 {msg}', 'blue'))
                except Exception as e:
                    self.exec_logger.warning(f'Unable to subscribe to control topic : {e}')
                    self.controller = None
                publisher_config = MQTT_CONTROL_CONFIG.copy()
                publisher_config['topic'] = MQTT_CONTROL_CONFIG['ctrl_topic']
                publisher_config.pop('ctrl_topic')

                def on_message(client, userdata, message):
                    command = message.payload.decode('utf-8')
                    self.exec_logger.debug(f'Received command {command}')
                    self._process_commands(command)

                self.controller.on_message = on_message
            else:
                self.controller = None
                self.exec_logger.warning('No connection to control broker.'
                                         ' Use python/ipython to interact with OhmPi object...')

    @staticmethod
    
    def append_and_save(filename: str, last_measurement: dict, cmd_id=None):
        """Appends and saves the last measurement dict.

        Parameters
        ----------
        filename : str
            filename to save the last measurement dataframe
        last_measurement : dict
            Last measurement taken in the form of a python dictionary
        cmd_id : str, optional
            Unique command identifier
        """
        last_measurement = deepcopy(last_measurement)
        if 'fulldata' in last_measurement:
            d = last_measurement['fulldata']
            n = d.shape[0]
            if n > 1:
                idic = dict(zip(['i' + str(i) for i in range(n)], d[:, 0]))
                udic = dict(zip(['u' + str(i) for i in range(n)], d[:, 1]))
                tdic = dict(zip(['t' + str(i) for i in range(n)], d[:, 2]))
                uxdic = dict(zip(['ux' + str(i) for i in range(n)], d[:, 3]))
                uydic = dict(zip(['uy' + str(i) for i in range(n)], d[:, 4]))
                last_measurement.update(idic)
                last_measurement.update(udic)
                last_measurement.update(tdic)
                last_measurement.update(uxdic)
                last_measurement.update(uydic)
            last_measurement.pop('fulldata')

        if os.path.isfile(filename):
            # Load data file and append data to it
            with open(filename, 'a') as f:
                w = csv.DictWriter(f, last_measurement.keys())
                w.writerow(last_measurement)
                # last_measurement.to_csv(f, header=False)
        else:
            # create data file and add headers
            with open(filename, 'a') as f:
                w = csv.DictWriter(f, last_measurement.keys())
                w.writeheader()
                w.writerow(last_measurement)

    def _compute_tx_volt(self, best_tx_injtime=0.1, strategy='vmax', tx_volt=5, autogain=True):
        """Estimates best Tx voltage based on different strategies.
        At first a half-cycle is made for a short duration with a fixed
        known voltage. This gives us Iab and Rab. We also measure Vmn.
        A constant c = vmn/iab is computed (only depends on geometric
        factor and ground resistivity, that doesn't change during a
        quadrupole). Then depending on the strategy, we compute which
        vab to inject to reach the minimum/maximum Iab current or
        min/max Vmn.
        This function also compute the polarity on Vmn (on which pin
        of the ADS1115 we need to measure Vmn to get the positive value).

        Parameters
        ----------
        best_tx_injtime : float, optional
            Time in milliseconds for the half-cycle used to compute Rab.
        strategy : str, optional
            Either:
            - vmax : compute Vab to reach a maximum Iab and Vmn
            - constant : apply given Vab
        tx_volt : float, optional
            Voltage to apply for guessing the best voltage. 5 V applied
            by default. If strategy "constant" is chosen, constant voltage
            to applied is "tx_volt".

        Returns
        -------
        vab : float
            Proposed Vab according to the given strategy.
        polarity : int
            Either 1 or -1 to know on which pin of the ADS the Vmn is measured.
        """

        # hardware limits
        voltage_min = 10.  # mV
        voltage_max = 4500.
        current_min = voltage_min / (self.r_shunt * 50)  # mA
        current_max = voltage_max / (self.r_shunt * 50)
        tx_max = 50.  # volt

        # check of volt
        volt = tx_volt
        if volt > tx_max:
            self.exec_logger.warning('Sorry, cannot inject more than 50 V, set it back to 5 V')
            volt = 5.

        # redefined the pin of the mcp (needed when relays are connected)
        self.pin0 = self.mcp_board.get_pin(0)
        self.pin0.direction = Direction.OUTPUT
        self.pin0.value = False
        self.pin1 = self.mcp_board.get_pin(1)
        self.pin1.direction = Direction.OUTPUT
        self.pin1.value = False

        # select a polarity to start with
        self.pin0.value = True
        self.pin1.value = False
        
        
        if strategy == 'constant':
            vab = volt

            self.DPS.write_register(0x0000, volt, 2)
            self.DPS.write_register(0x09, 1)  # DPS5005 on
            time.sleep(best_tx_injtime)  # inject for given tx time
            self.ads_current = ads.ADS1115(self.i2c, gain=2 / 3, data_rate=860, address=self.ads_current_address)
            self.ads_voltage = ads.ADS1115(self.i2c, gain=2 / 3, data_rate=860, address=self.ads_voltage_address)
            # autogain
            if autogain:
                gain_current = self._gain_auto(AnalogIn(self.ads_current, ads.P0))
                gain_voltage0 = self._gain_auto(AnalogIn(self.ads_voltage, ads.P0))
                gain_voltage2 = self._gain_auto(AnalogIn(self.ads_voltage, ads.P2))
                gain_voltage = np.min([gain_voltage0, gain_voltage2])  # TODO: separate gain for P0 and P2
                self.ads_current = ads.ADS1115(self.i2c, gain=gain_current, data_rate=860, address=self.ads_current_address)
                self.ads_voltage = ads.ADS1115(self.i2c, gain=gain_voltage, data_rate=860, address=self.ads_voltage_address)
            # we measure the voltage on both A0 and A2 to guess the polarity
            I = AnalogIn(self.ads_current, ads.P0).voltage * 1000. / 50 / self.r_shunt  # noqa measure current
            U0 = AnalogIn(self.ads_voltage, ads.P0).voltage * 1000. * self.U0_factor + self.U0_offset  # noqa measure voltage
            U2 = AnalogIn(self.ads_voltage, ads.P2).voltage * 1000. * self.U2_factor + self.U2_offset # noqa
            # check polarity
            polarity = 1  # by default, we guessed it right
            vmn = U0
            if U0 < 0:  # we guessed it wrong, let's use a correction factor
                polarity = -1
                vmn = U2
        
        elif strategy == 'vmax':
            volt = 5
            # implement different strategies
            I=0
            vmn=0
            count=0
            while I < 3 or abs(vmn) < 20:  #TODO: hardware related - place in config
            
                if count > 0 :
                    volt = volt + 2
                count=count+1
                if volt > tx_max:
                    break
        
                # set voltage for test
                self.DPS.write_register(0x0000, volt, 2)
                if count==1:
                    self.DPS.write_register(0x09, 1)  # DPS5005 on
                    # inject for given tx time
                time.sleep(best_tx_injtime)
                self.ads_current = ads.ADS1115(self.i2c, gain=2 / 3, data_rate=860, address=self.ads_current_address)
                self.ads_current.mode = Mode.CONTINUOUS
                self.ads_voltage = ads.ADS1115(self.i2c, gain=2 / 3, data_rate=860, address=self.ads_voltage_address)
                self.ads_voltage.mode = Mode.CONTINUOUS
                # No need to use autogain to save time
                I = AnalogIn(self.ads_current, ads.P0).voltage * 1000. / 50 / self.r_shunt  # noqa measure current
                U0 = AnalogIn(self.ads_voltage, ads.P0).voltage * 1000. * self.U0_factor + self.U0_offset # noqa measure voltage
                U2 = AnalogIn(self.ads_voltage, ads.P2).voltage * 1000. * self.U2_factor + self.U2_offset # noqa

                # check polarity
                polarity = 1  # by default, we guessed it right
                vmn = U0
                if U0 < 0:  # we guessed it wrong, let's use a correction factor
                    polarity = -1
                    vmn = U2
                    
            n = 0
            while (abs(vmn) > voltage_max or I > current_max) and volt>0:  #If starting voltage is too high, need to lower it down
                # print('we are out of range! so decreasing volt')
                volt = volt - 2
                self.DPS.write_register(0x0000, volt, 2)
                #self.DPS.write_register(0x09, 1)  # DPS5005 on
                I = AnalogIn(self.ads_current, ads.P0).voltage * 1000. / 50 / self.r_shunt
                U0 = AnalogIn(self.ads_voltage, ads.P0).voltage * 1000. * self.U0_factor + self.U0_offset
                U2 = AnalogIn(self.ads_voltage, ads.P2).voltage * 1000. * self.U2_factor + self.U2_offset
                polarity = 1  # by default, we guessed it right
                vmn = U0
                if U0 < 0:  # we guessed it wrong, let's use a correction factor
                    polarity = -1
                    vmn = U2
                n+=1
                if n > 25 :   
                    break
                        
            factor_I = (current_max) / I
            factor_vmn = voltage_max / vmn
            factor = factor_I
            if factor_I > factor_vmn:
                factor = factor_vmn
            vab = factor * volt * 0.9
            if vab > tx_max:
                vab = tx_max

        elif strategy == 'vmin':
            # implement different strategy
            I=20
            vmn=400
            count=0
            while I > 10 or abs(vmn) > 300 :  #TODO: hardware related - place in config
                if count > 0 :
                    volt = volt - 2
                count=count+1
                if volt > 50:
                    break

                # set voltage for test
                self.DPS.write_register(0x0000, volt, 2)
                if count==1:
                    self.DPS.write_register(0x09, 1)  # DPS5005 on
                time.sleep(best_tx_injtime)  # inject for given tx time
                self.ads_current = ads.ADS1115(self.i2c, gain=2 / 3, data_rate=860, address=self.ads_current_address)
                self.ads_current.mode = Mode.CONTINUOUS
                self.ads_voltage = ads.ADS1115(self.i2c, gain=2 / 3, data_rate=860, address=self.ads_voltage_address)
                self.ads_voltage.mode = Mode.CONTINUOUS                # we measure the voltage on both A0 and A2 to guess the polarity
                I = AnalogIn(self.ads_current, ads.P0).voltage * 1000. / 50 / self.r_shunt  # noqa measure current
                U0 = AnalogIn(self.ads_voltage, ads.P0).voltage * 1000.  # noqa measure voltage
                U2 = AnalogIn(self.ads_voltage, ads.P2).voltage * 1000.  # noqa

                # check polarity
                polarity = 1  # by default, we guessed it right
                vmn = U0
                if U0 < 0:  # we guessed it wrong, let's use a correction factor
                    polarity = -1
                    vmn = U2
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

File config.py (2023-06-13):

import logging
from utils import get_platform

from paho.mqtt.client import MQTTv31

_, on_pi = get_platform()
# DEFINE THE ID OF YOUR OhmPi
ohmpi_id = '0001' if on_pi else 'XXXX'
# DEFINE YOUR MQTT BROKER (DEFAULT: 'localhost')
mqtt_broker = 'localhost' if on_pi else 'NAME_YOUR_BROKER_WHEN_IN_SIMULATION_MODE_HERE'
# DEFINE THE SUFFIX TO ADD TO YOUR LOGS FILES
logging_suffix = ''

# OhmPi configuration
OHMPI_CONFIG = {
    'id': ohmpi_id,  # Unique identifier of the OhmPi board (string)
    'R_shunt': 2,  # Shunt resistance in Ohms
    'Imax': 4800 / 50 / 2,  # Maximum current
    'coef_p2': 2.50,  # slope for current conversion for ADS.P2, measurement in V/V
    'nb_samples': 20,  # Max value 10 # was named integer before...
    'version': 2,  # Is this still needed?
    'max_elec': 64,
    'board_addresses': {'A': 0x70, 'B': 0x71, 'M': 0x72, 'N': 0x73},  # CHECK IF YOUR BOARDS HAVE THESE ADDRESSES
    'settings': 'ohmpi_settings.json',  # INSERT YOUR FAVORITE SETTINGS FILE HERE
    'board_version': 'mb.2023.0.0',#,'22.10',
    'mcp_board_address': 0x21,
    'i2c_mux_address': 2,  # 2 if on same bus as the measurement board, 4 if additional bus
    'U0_offset': 0, # offset for the ads channel U0 voltage
    'U2_offset': 0, # offset for the ads channel U2 voltage
    'U0_factor': 1, # scaling factor for the ads channel U0 voltage
    'U2_factor': 1 # scaling factor for the ads channel U2 voltage
}  # TODO: add a dictionary with INA models and associated gain values

# SET THE LOGGING LEVELS, MQTT BROKERS AND MQTT OPTIONS ACCORDING TO YOUR NEEDS
# Execution logging configuration
EXEC_LOGGING_CONFIG = {
    'logging_level': logging.INFO,
    'log_file_logging_level': logging.DEBUG,
    'logging_to_console': True,
    'file_name': f'exec{logging_suffix}.log',
    'max_bytes': 262144,
    'backup_count': 30,
    'when': 'd',
    'interval': 1
}

# Data logging configuration
DATA_LOGGING_CONFIG = {
    'logging_level': logging.INFO,
    'logging_to_console': True,
    'file_name': f'data{logging_suffix}.log',
    'max_bytes': 16777216,
    'backup_count': 1024,
    'when': 'd',
    'interval': 1
}

# State of Health logging configuration (For a future release)
SOH_LOGGING_CONFIG = {
    'logging_level': logging.INFO,
    'logging_to_console': True,
    'file_name': 'soh.log',
    'max_bytes': 16777216,
    'backup_count': 1024,
    'when': 'd',
    'interval': 1
}

# MQTT logging configuration parameters
MQTT_LOGGING_CONFIG = {
    'hostname': mqtt_broker,
    'port': 1883,
    'qos': 2,
    'retain': False,
    'keepalive': 60,
    'will': None,
    'auth': {'username': 'mqtt_user', 'password': 'mqtt_password'},
    'tls': None,
    'protocol': MQTTv31,
    'transport': 'tcp',
    'client_id': f'{OHMPI_CONFIG["id"]}',
    'exec_topic': f'ohmpi_{OHMPI_CONFIG["id"]}/exec',
    'exec_logging_level': logging.DEBUG,
    'data_topic': f'ohmpi_{OHMPI_CONFIG["id"]}/data',
    'data_logging_level': DATA_LOGGING_CONFIG['logging_level'],
    'soh_topic': f'ohmpi_{OHMPI_CONFIG["id"]}/soh',
    'soh_logging_level': SOH_LOGGING_CONFIG['logging_level']
}

# MQTT control configuration parameters
MQTT_CONTROL_CONFIG = {
    'hostname': mqtt_broker,
    'port': 1883,
    'qos': 2,
    'retain': False,
    'keepalive': 60,
    'will': None,
    'auth': {'username': 'mqtt_user', 'password': 'mqtt_password'},
    'tls': None,
    'protocol': MQTTv31,
    'transport': 'tcp',
    'client_id': f'{OHMPI_CONFIG["id"]}',
    'ctrl_topic': f'ohmpi_{OHMPI_CONFIG["id"]}/ctrl'
}

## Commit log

2022-11-21 Adds draft kicad schematics for MUX boards for 8 electrodes with ABMN roles. It includes 4:1 multiplexing on M roles for multichannel acquisition.
    [MUX_1_relay.kicad_sch, MUX_1_relay_MN.kicad_sch, MUX_board_v2024.kicad_pcb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]
2022-11-21 Updates and rename MUX_v2024_relay_board
    [MUX_1_relay.kicad_sch, MUX_1_relay_MN.kicad_sch, MUX_v2024_relay_board.kicad_pcb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]
2022-11-21 Renames MUX_v2024_relay_board
    [MUX_1_relay.kicad_sch, MUX_1_relay_MN.kicad_sch, MUX_board_v2024.kicad_pcb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]
2022-11-24 Modifies schematics for scenario with single MN relays and analog multiplexers for roles M1 M2 and N. This assumes that the measurement board is modified to allow simultaneous measurements of M1 and 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
    [MUX_v2024_relay_board.kicad_sch]
2022-12-14 Updates relay board to versatile 32 relays board addressing 16 electrodes and 2 roles or 8 electrodes and 4 roles
    [MUX_1_relay.kicad_sch, MUX_1_relay_MN.kicad_sch, MUX_v2024_relay_board.kicad_pcb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]
2022-12-14 Updates MUX relay board
    [MUX_v2024_relay_board_32.kicad_pcb]
2022-12-15 Fixes last errors on pcb
    [MUX_v2024_relay_board_32.kicad_pcb, MUX_v2024_relay_board_32.kicad_sch]
2022-12-16 Improves annotations on pcb board
    [MUX_v2024_relay_board_32.kicad_pcb]
2023-02-14 Adds MUX addressing tables
    [MUX_settings.csv, addresses_table_2roles.csv, addresses_table_4roles.csv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]
2023-02-14 Refactor directory MUX board 2024.0.0
    [Addresses_table.xlsx, MUX_1_relay.kicad_sch, MUX_settings.csv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]
2023-02-14 Refactors MUX board 2024.0.0
    [Addresses_table.xlsx, MUX_1_relay.kicad_sch, MUX_1_relay_MN.kicad_sch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]
2023-02-14 Updates mux v2024 addressing
    [MUX_settings.csv, addresses_table_4roles.csv, compiled_mux_addressing_table.csv]
2023-02-14 Adds MUX board 2024 capability
2023-02-15 improves mux addressing and adds switch_mux_quad function
2023-04-07 Fixes autogain False/True conditions
    [ohmpi.py]
2023-04-07 Adds duty cycle in run_measurement to shorten no-injection duration if needed
    [ohmpi.py]
2023-04-15 update test_mux function and fix some bugs
    [ohmpi.py]
2023-04-23 Correction of the continuous mode, for a good measurement.
    [ohmpi.py]
2023-04-26 update measurement board schematics and circuit
    [Current_injection_and_measurement.kicad_sch, Relay_switch_dsp.kicad_sch, Vmn_measurement.kicad_sch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]
2023-05-10 update pcb
    [mb.2024.0.0.kicad_sch, mux.2023.0.0.fzz, mux.2023.0.1.fzz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]
2023-06-06 correction of ads continious mode inversion between current and voltage
    [ohmpi.py]
2023-06-06 max current allow
2023-06-07 adds second I2C bus capability for mux and fix bugs
    [ohmpi.py]
2023-06-07 fixes plot in realtime
    [plots.py]
2023-06-07 Adds second i2c bus capability
2023-06-07 fixes plots in real_time
    [plots.py]
2023-06-07 update last version with nex examples
    [simple_measurement.csv]
2023-06-07 add test_led function
    [simple_measurement.csv]
2023-06-07 Adds battery_level readings
2023-06-07 Fixes rs_check and export dir and name
    [ohmpi.py]
2023-06-07 Fixes rs check issue from merge
    [ohmpi.py]
2023-06-08 Fixes sampling interval strategy (minimum sampling interval when reading u0 and u2 is 10 ms)
    [ohmpi.py]
2023-06-13 issue #109 : add U0 and U2 factors
    [config.py, ohmpi.py]
2023-06-13 issue # 109: now we added an offset
    [config.py, ohmpi.py]
